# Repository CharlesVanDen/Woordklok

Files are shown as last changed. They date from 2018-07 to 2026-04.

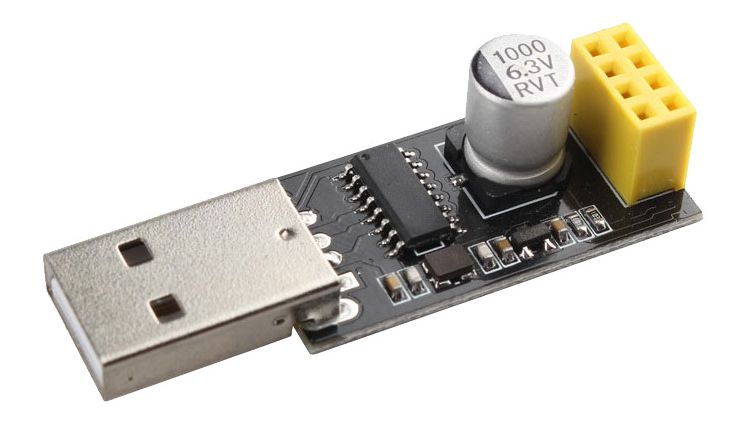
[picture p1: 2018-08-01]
img/ESP01adapter.png

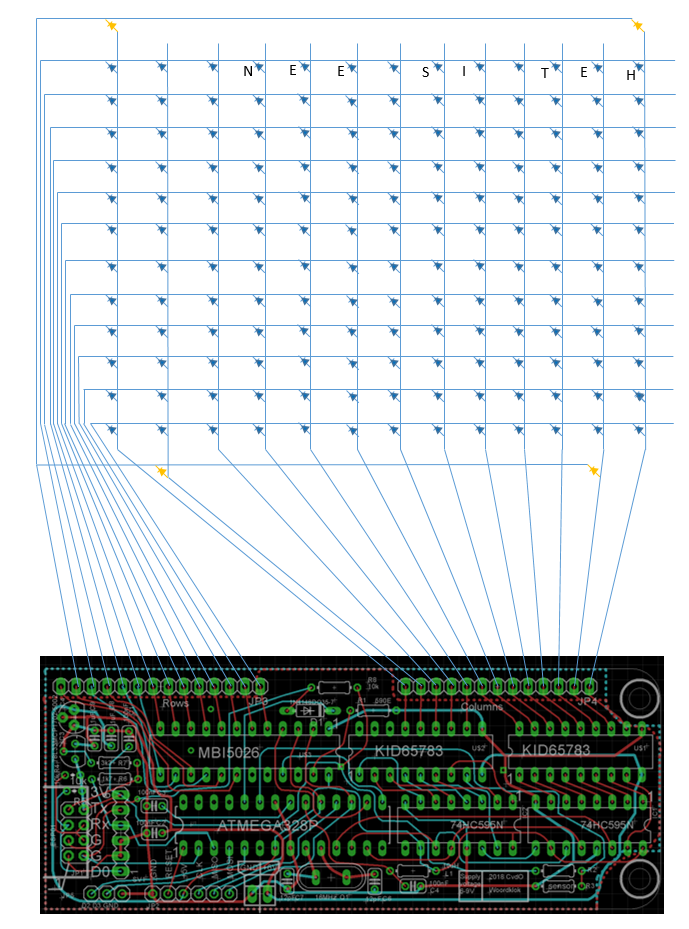
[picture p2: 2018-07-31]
img/Schema hoe de LEDs aan te sluiten.png

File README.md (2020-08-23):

# Woordklok
Alternatieve besturing voor de woordklok van Samenkopen 2016
Dit project bestaat uit:
* een pcb met daarop een ATMEGA en andere elektronica
* een ESP01
* software voor de ATMEGA (Atmel Studio)
* software voor de ESP (Arduino)

Klik op Wiki (hierboven) voor meer informatie

CONTACT: Klik op Wiki (hierboven) en daarna op Bestellen

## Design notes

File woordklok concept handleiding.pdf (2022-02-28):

## Concept

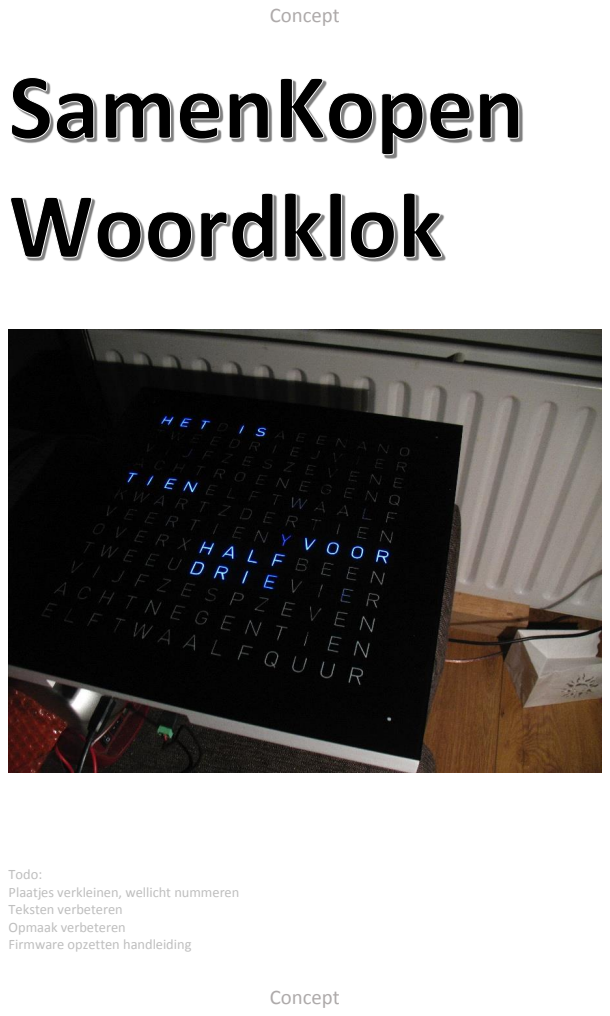
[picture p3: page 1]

Todo:
Plaatjes verkleinen, wellicht nummeren
Teksten verbeteren
Opmaak verbeteren
Firmware opzetten handleiding

# Handleiding in tekst:

Solderen van de LED's
De afstand tussen de LED's is zo dat je geen draden nodig hebt maar van LED naar LED de pootjes kan buigen en verbinden.
Als je de controller voor je hebt met de USB kabel naar je toe gericht, dan zit het positieve deel van de matrix rechtsboven en het negatieve deel linksboven.
Na het solderen krijg je dus verticale en horizontale lijnen. De verticale lijnen(boven naar beneden) zijn de plus(Anode) en de horizontale lijnen(links naar rechts) zijn de min(Kathode).

De magneten
In de doos zitten 16 zeer sterke neodymium magneten. Laat ze niet tegen elkaar aan knallen, dan spatten ze uit elkaar!
1. Vind de polariteit van elke magneet. Bij het plaatsen moeten ze allemaal op dezelfde manier georiënteerd zitten. Bij verkeerde polariteit stoten ze anders af
2. Lijm met seconde of andere sterke lijm eerst 8 magneten in de pockets die in het frame zitten. Druk ze goed aan zodat ze stevig tegen de bodem zitten
3. Leg na het uitharden van de lijm een stukje dun karton op elke magneet.
4. Leg op elk stuk karton een magneet, deze zal direct aangetrokken worden door de andere magneet. Probeer de magneet zo gecentreerd mogelijk te krijgen.
5. Doe een klein druppeltje sterke lijm op elke magneet.
6. Pak het frontpanel en probeer deze zo recht mogelijk op het frame te leggen. Dit doe je door te controleren of het frontpanel perfect aansluit bij elke zijkant van het frame.
7. Leg nu een gewicht, zoals een beker, op de locatie waar elke magneet zit.
8. Niet meer bewegen! Geef voldoende tijd om de lijm te laten uitharden. Haal de kartonnetjes daarna weg en je frontpanel zit goed

Diffuseren van de LED's
Voor een betere lichtverdeling leg je tussen het frame en het frontpanel de witte folie, die je voorzichtig van het frontpanel hebt getrokken. Eventueel plak je deze folie vast.

Bevestigen van de controller aan het frame
Doe wat lijm op de afstandsbusjes van de controller print. Druk de controller print nu stevig tegen de bestemde plek op het frame. Handig om dit eerst te doen voordat je de draden naar de LED's soldeer!

Touch sensoren
De touch sensoren hebben twee aansluitingen aan de achterkant(het groene raster). Sluit maar één draad aan. Het soldeervlak van het raster krijgt géén draad.
Soldeer eerst een draad aan de touch sensor voordat je hem op het frame plakt. Dat is eenvoudiger.

Lichtsensor
De lichtsensor plak je in de sleuf aan de bovenkant van het frame. Het handigste is om twee draden met voldoende lengte te pakken en deze met een boormachine in elkaar te twisten. Dan soldeer je die aan de lichtsensor en die gaat dan in een rechte lijn naar beneden naar de controller. Als je deze draad onder de LED's doorvlecht, dan blijft deze mooi op zijn plek!

# Deel I

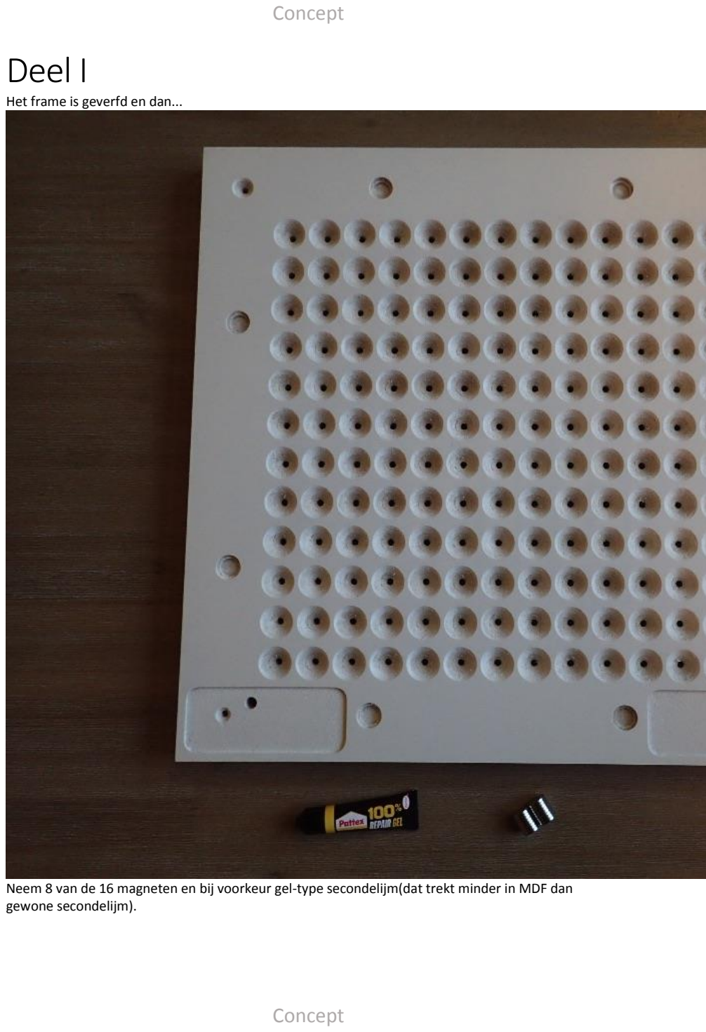
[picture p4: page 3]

Het frame is geverfd en dan...

Neem 8 van de 16 magneten en bij voorkeur gel-type secondelijm(dat trekt minder in MDF dan gewone secondelijm).

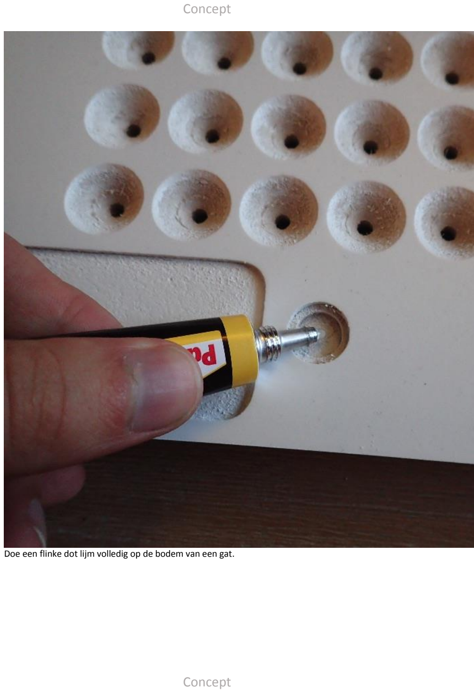
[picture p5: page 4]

Doe een flinke dot lijm volledig op de bodem van een gat.

Leg een magneet op het gat en druk deze met bijvoorbeeld een plastic pen het gat in.
Het gat en de magneet sluiten nauw aan dus het kan even wat kracht en moeite kosten! Druk niet door zodra hij er in glijdt want dan kan je door het frame drukken.

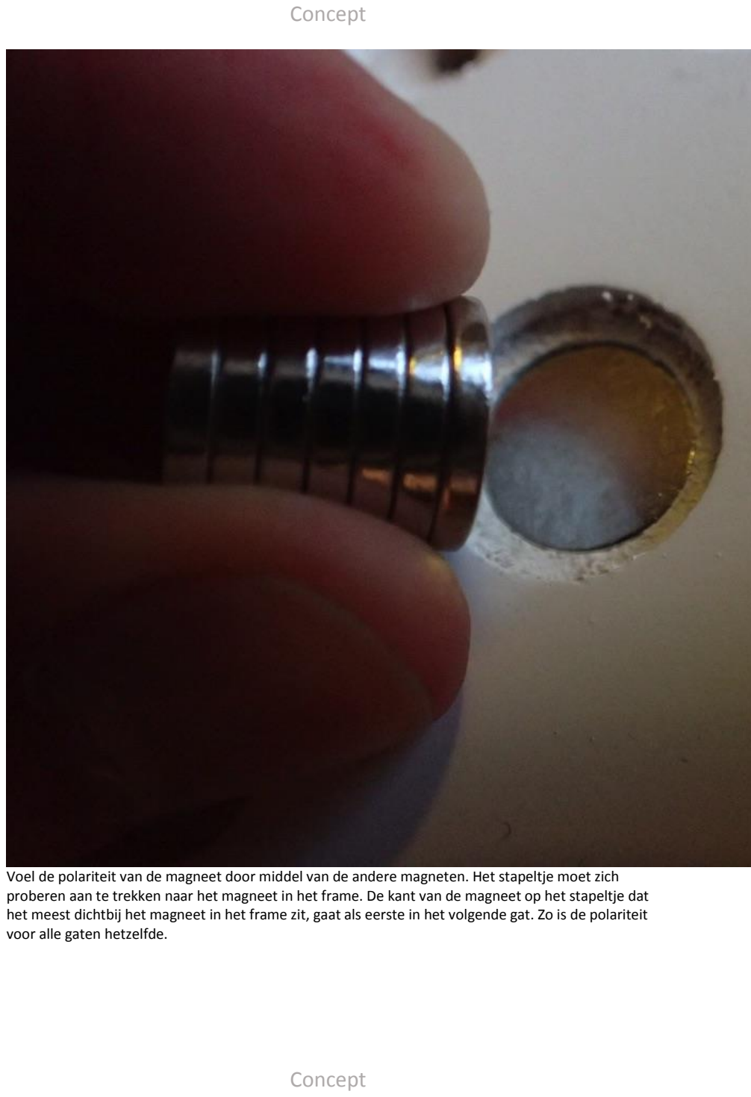
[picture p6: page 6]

Voel de polariteit van de magneet door middel van de andere magneten. Het stapeltje moet zich proberen aan te trekken naar het magneet in het frame. De kant van de magneet op het stapeltje dat het meest dichtbij het magneet in het frame zit, gaat als eerste in het volgende gat. Zo is de polariteit voor alle gaten hetzelfde.

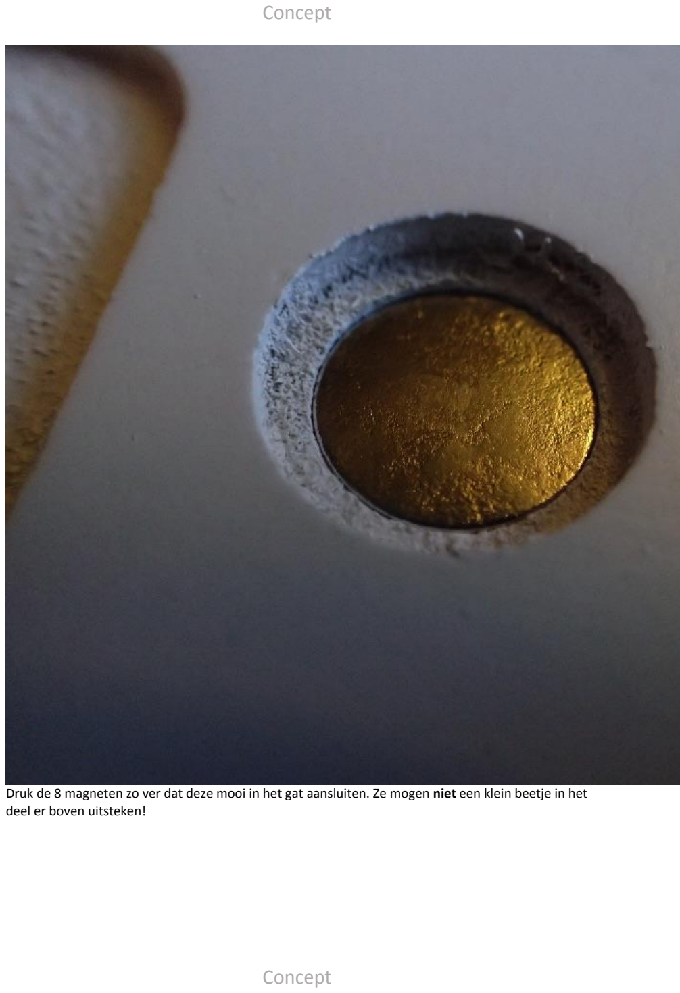
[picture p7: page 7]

Druk de 8 magneten zo ver dat deze mooi in het gat aansluiten. Ze mogen niet een klein beetje in het deel er boven uitsteken!

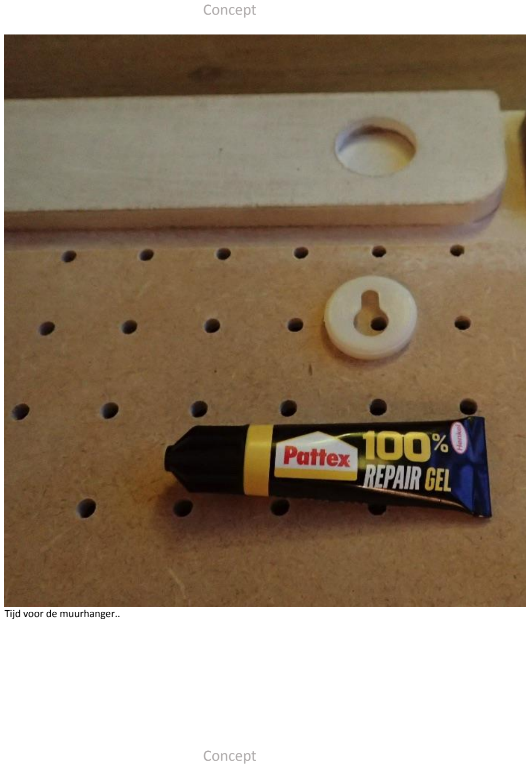
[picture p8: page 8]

Tijd voor de muurhanger..

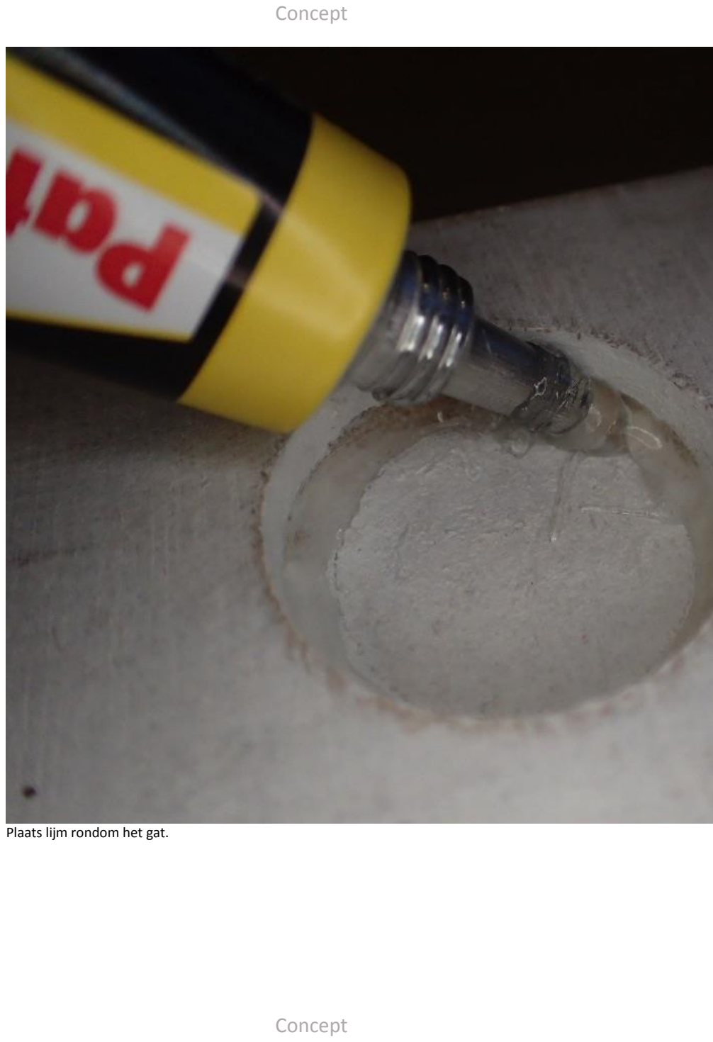
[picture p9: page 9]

Plaats lijm rondom het gat.

Leg de muurhanger op de juiste manier neer en druk deze het gat in. Hij zal een stukje verzonken liggen.

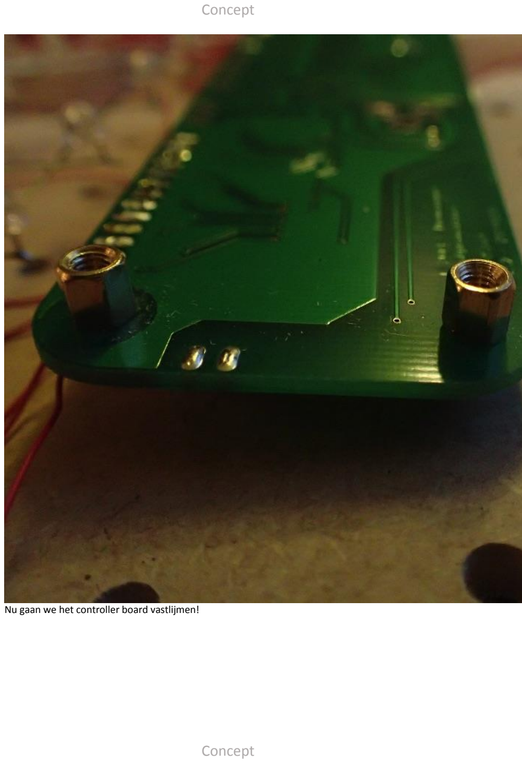
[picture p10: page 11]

Nu gaan we het controller board vastlijmen!

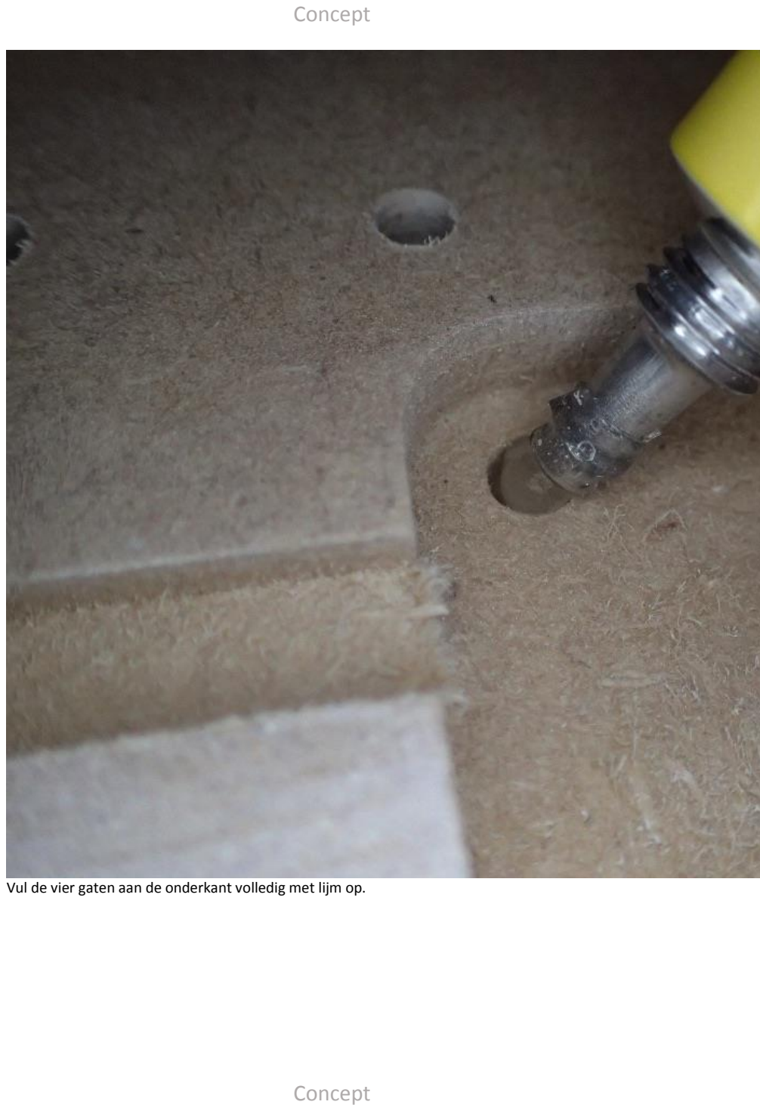
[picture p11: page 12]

Vul de vier gaten aan de onderkant volledig met lijm op.

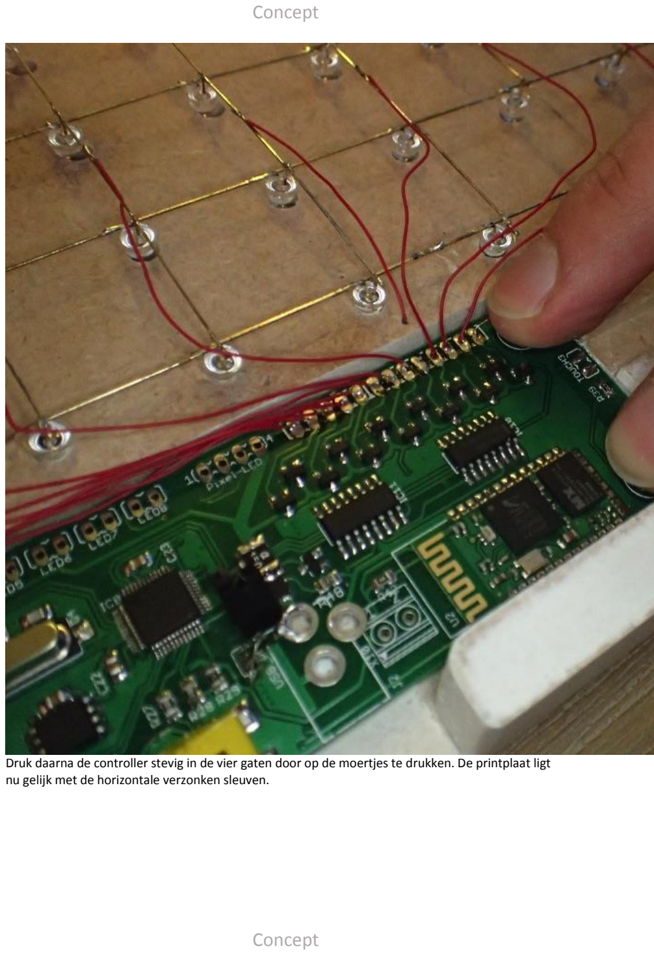
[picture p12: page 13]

Druk daarna de controller stevig in de vier gaten door op de moertjes te drukken. De printplaat ligt nu gelijk met de horizontale verzonken sleuven.

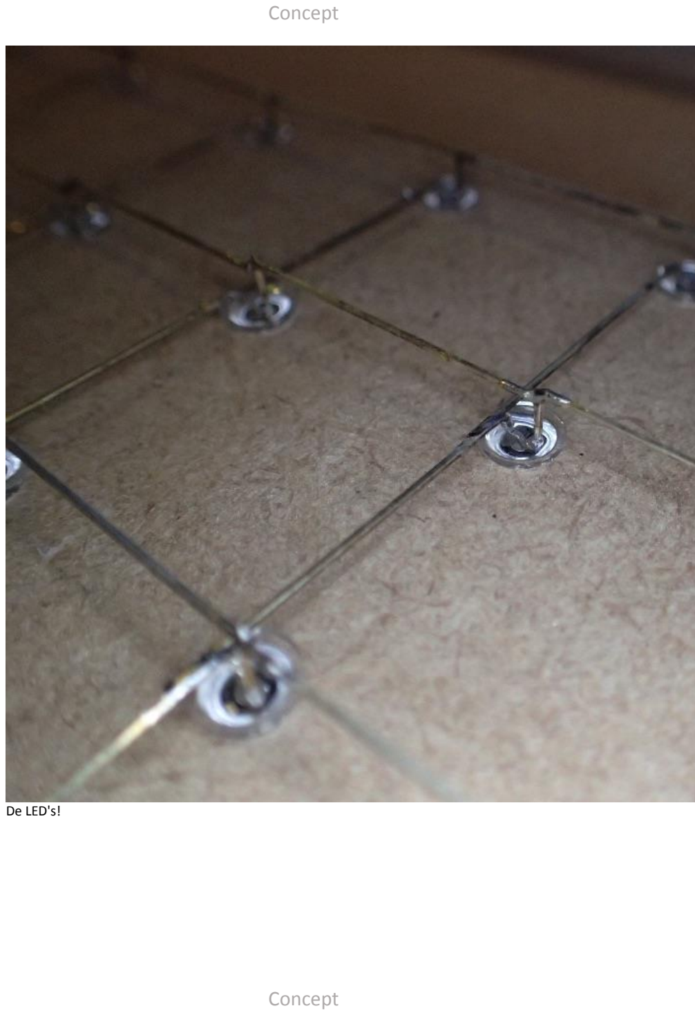
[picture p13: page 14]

De LED's!

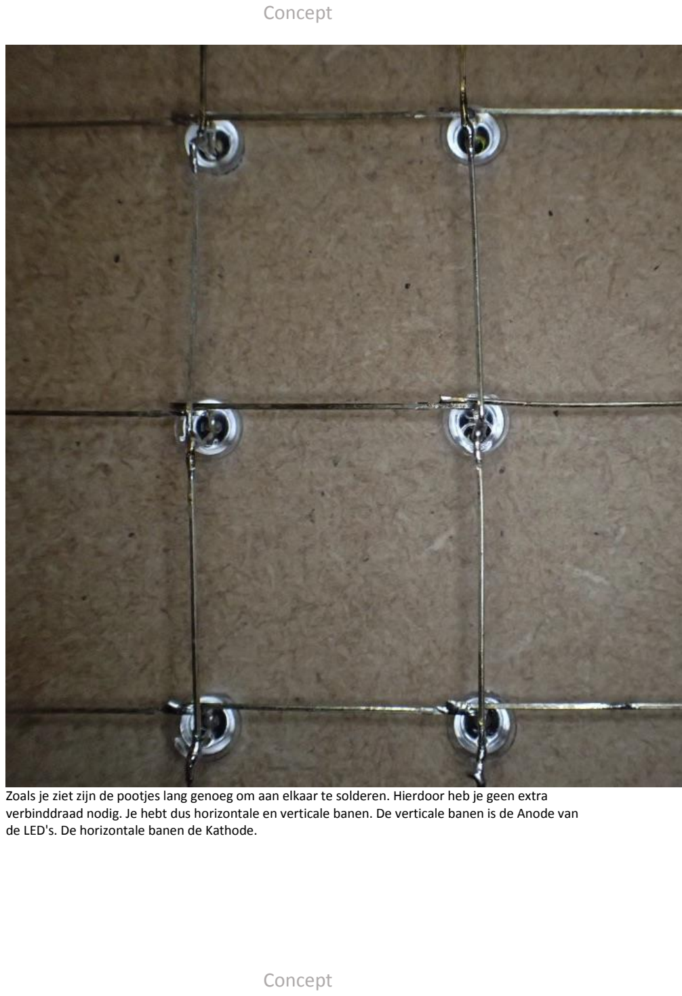
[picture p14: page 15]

Zoals je ziet zijn de pootjes lang genoeg om aan elkaar te solderen. Hierdoor heb je geen extra verbinddraad nodig. Je hebt dus horizontale en verticale banen. De verticale banen is de Anode van de LED's. De horizontale banen de Kathode.

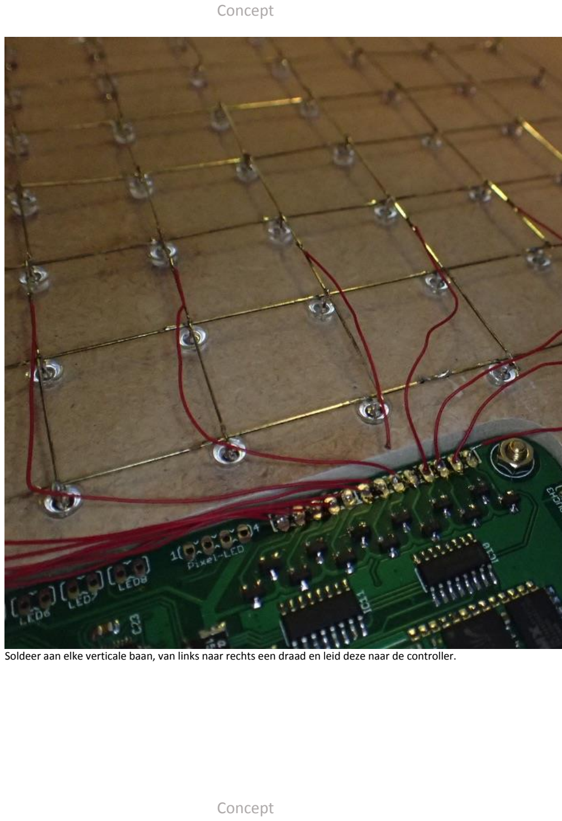
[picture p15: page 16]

Soldeer aan elke verticale baan, van links naar rechts een draad en leid deze naar de controller.

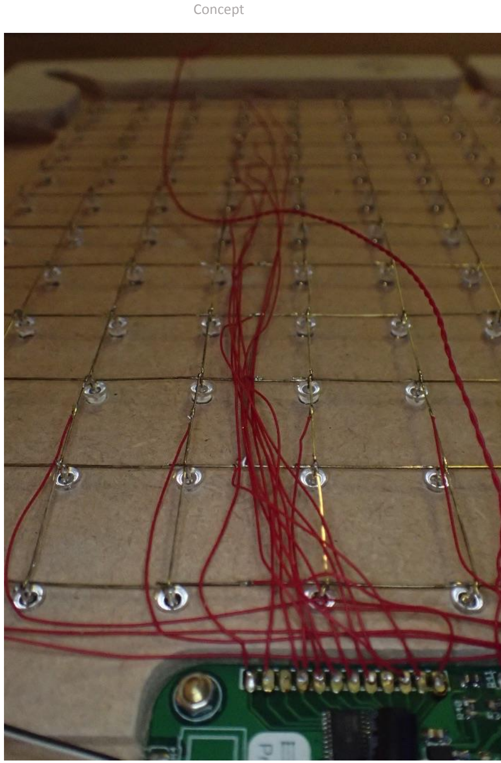
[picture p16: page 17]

Natuurlijk ook voor de verticale banen! Bij voorkeur laat je de draden onder de LED poten lopen(op de foto is dus fout), dan blijven de draden mooi tegen het frame aan zitten.

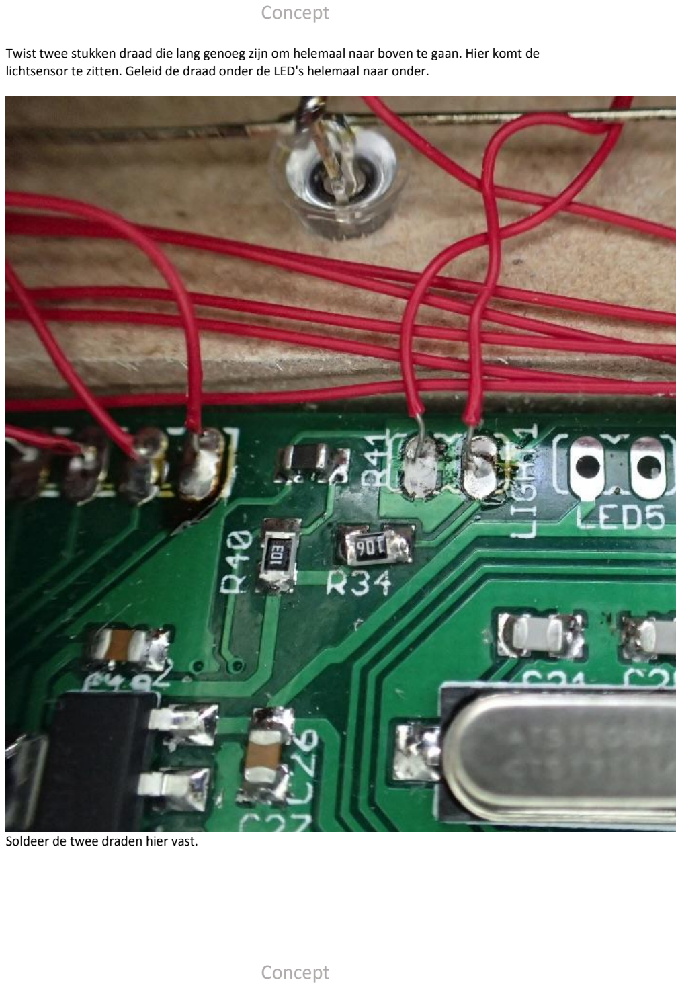
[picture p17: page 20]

Twist twee stukken draad die lang genoeg zijn om helemaal naar boven te gaan. Hier komt de lichtsensor te zitten. Geleid de draad onder de LED's helemaal naar onder.

Soldeer de twee draden hier vast.

# Deel II

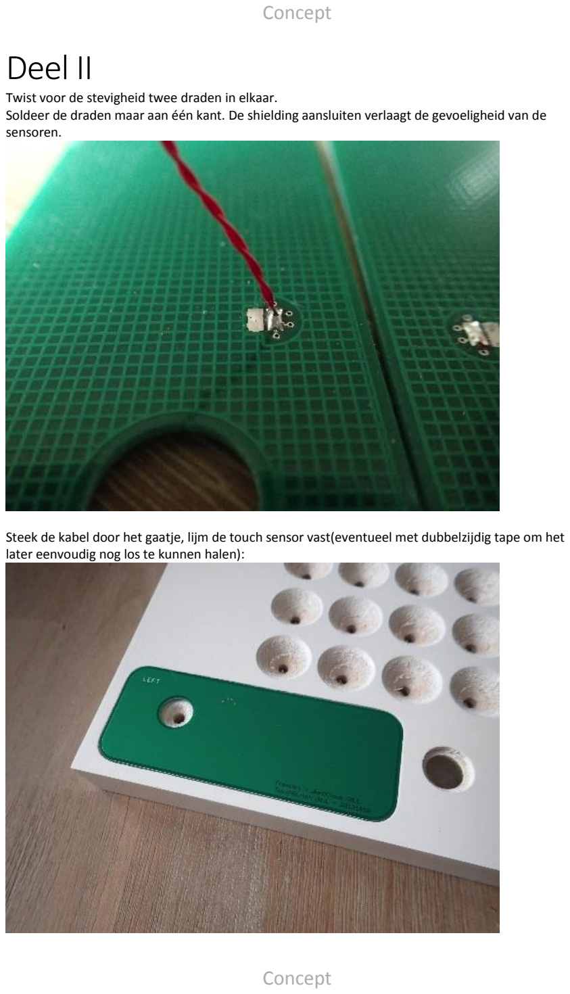
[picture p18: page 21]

Twist voor de stevigheid twee draden in elkaar.
Soldeer de draden maar aan één kant. De shielding aansluiten verlaagt de gevoeligheid van de sensoren.

Steek de kabel door het gaatje, lijm de touch sensor vast(eventueel met dubbelzijdig tape om het later eenvoudig nog los te kunnen halen):

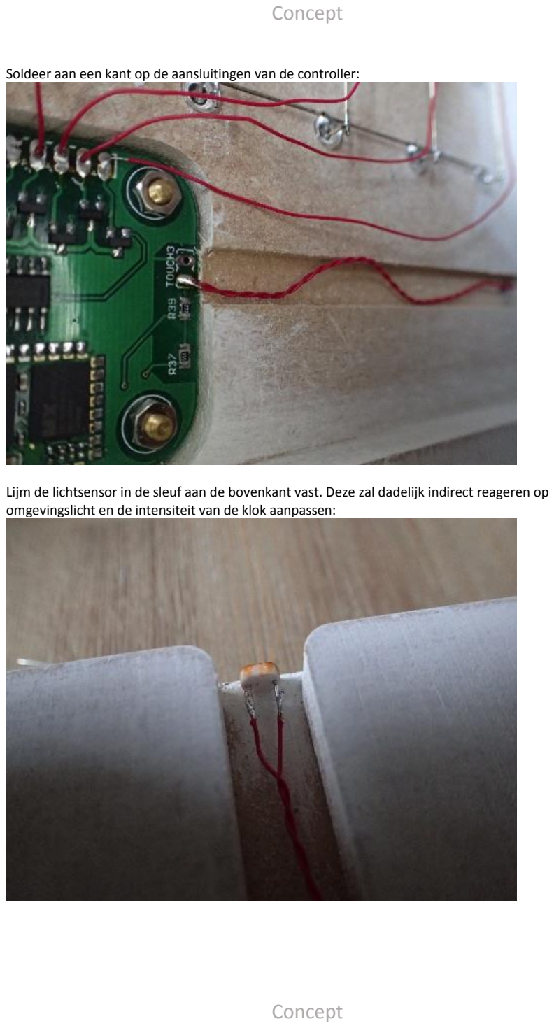
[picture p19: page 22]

Soldeer aan een kant op de aansluitingen van de controller:

Lijm de lichtsensor in de sleuf aan de bovenkant vast. Deze zal dadelijk indirect reageren op omgevingslicht en de intensiteit van de klok aanpassen:

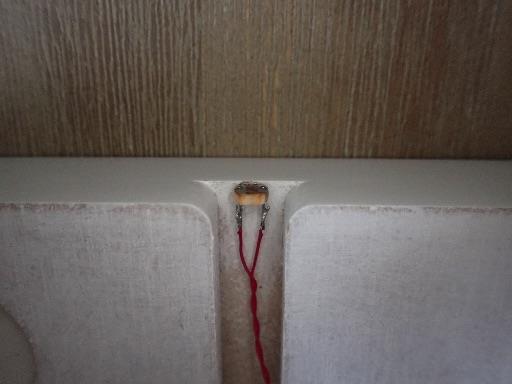
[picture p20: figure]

Frontpanel

De volgende onderdelen heb je nodig om het frontpanel aan de overige 8 magneten vast te lijmen. De flesjes bier kan je de komende 24 uur niet aanraken.

Kleine kartonnetjes(van bijvoorbeeld een pakje van de Knorr) zorgen er voor dat de magneten afstand van elkaar houden:

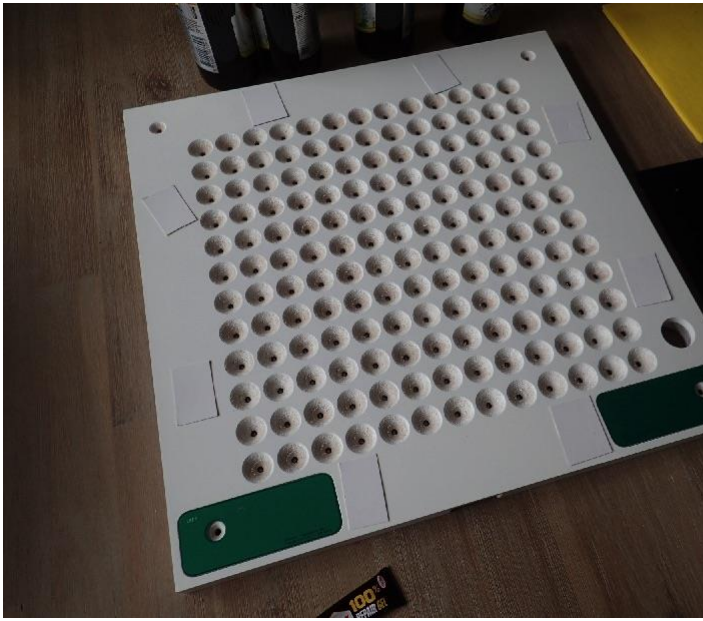
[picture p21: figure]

Leg de magneten hierop. Ze zullen automatisch centreren(dit kan je voelen!)

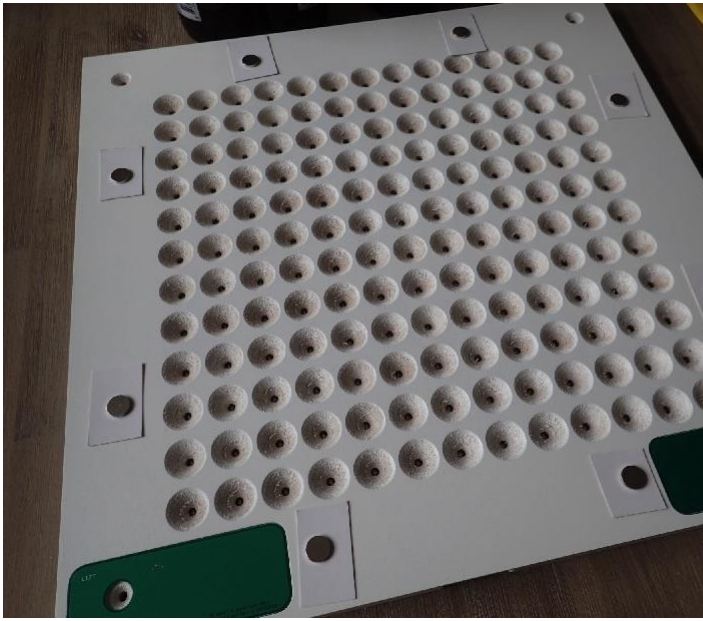
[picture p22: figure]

Voldoende lijm op elke magneet doen:

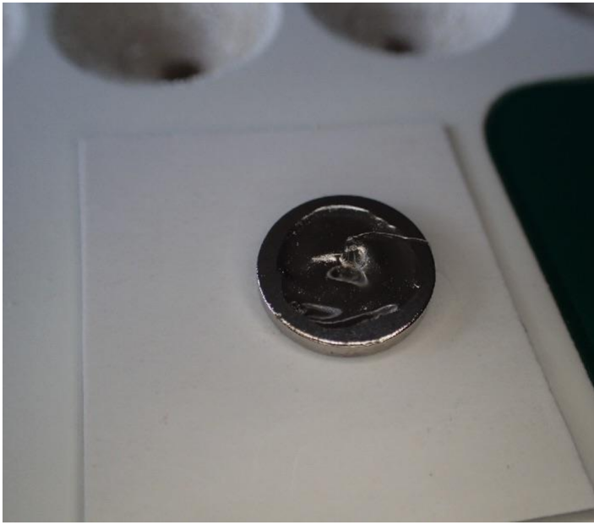
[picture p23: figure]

Leg het frontpanel zo recht mogelijk op de magneten:

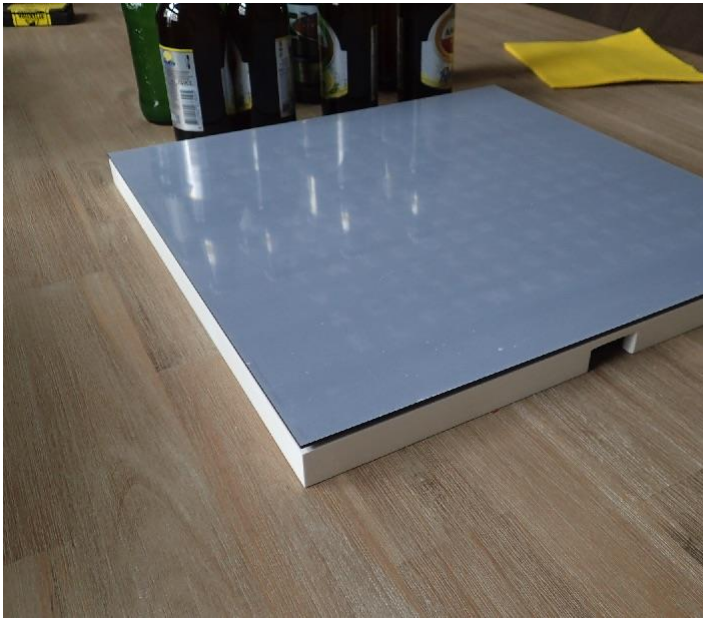
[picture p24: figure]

Zorg dat de uitlijning met alle randen klopt. Dit kan je controleren door een haaks blok tegen het frame aan te leggen:

Voscose doekjes die je in de keuken kan vinden zorgen er voor dat de flesjes/het gewicht het frontpanel niet kan beschadigen:

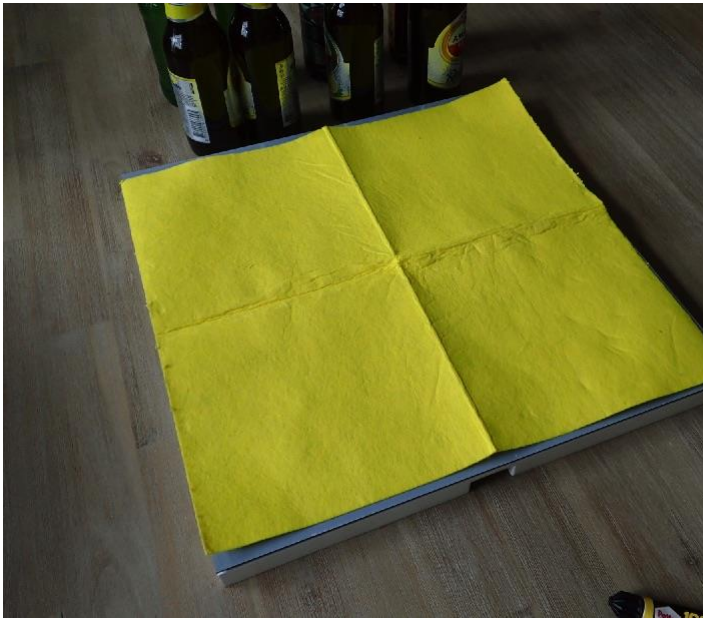
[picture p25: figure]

Zet de bierflesjes zo goed mogelijk op de magneten. Dit zorgt voor een strakke lijmverbinding.

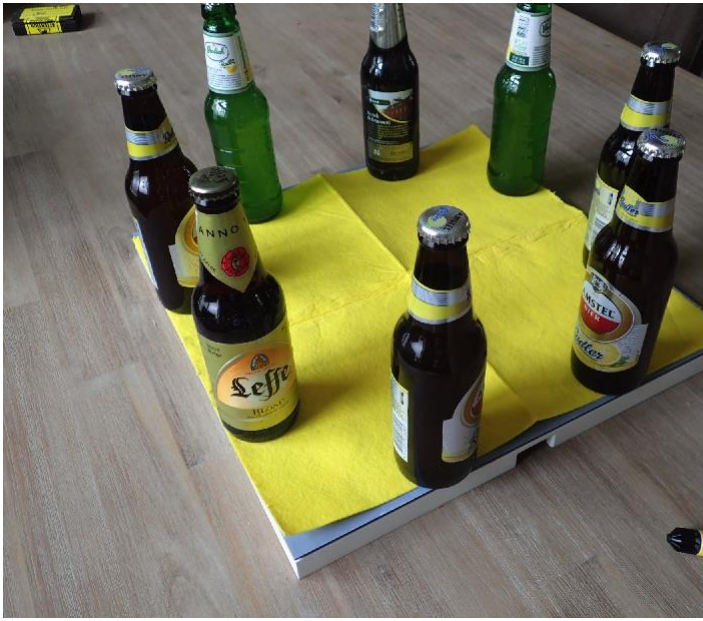
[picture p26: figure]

Nu zal je 24 uur moeten wachten tot de lijm volledig is uitgehard..

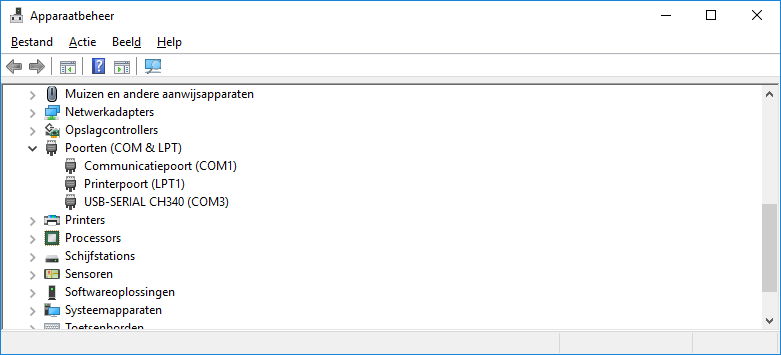
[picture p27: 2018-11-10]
img/apparaatbeheer2.png

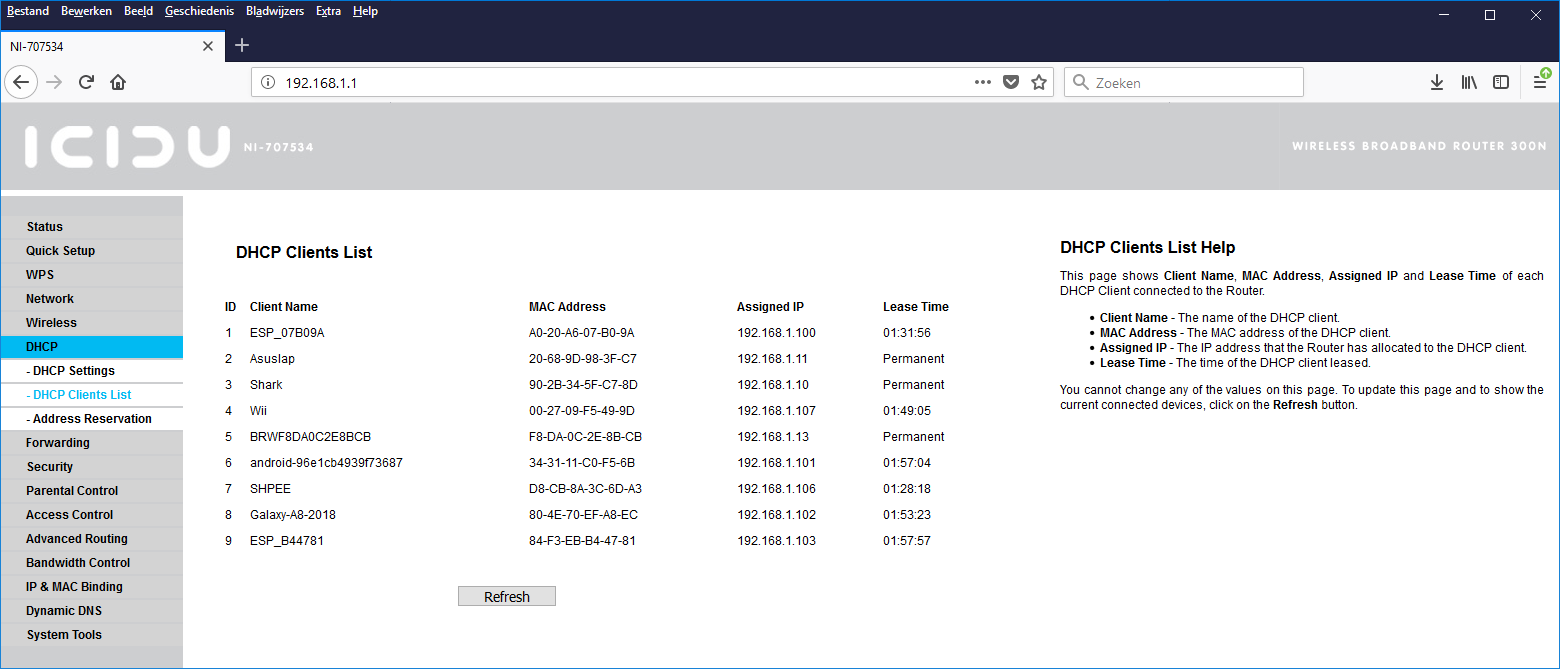
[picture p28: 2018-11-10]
img/router.png

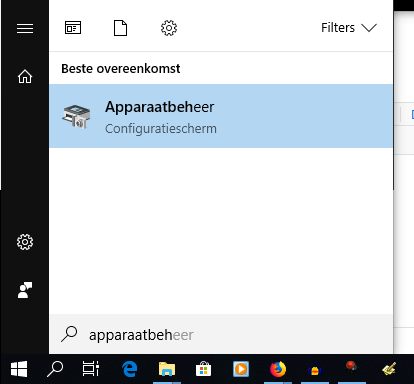
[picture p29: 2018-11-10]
img/apparaatbeheer.png

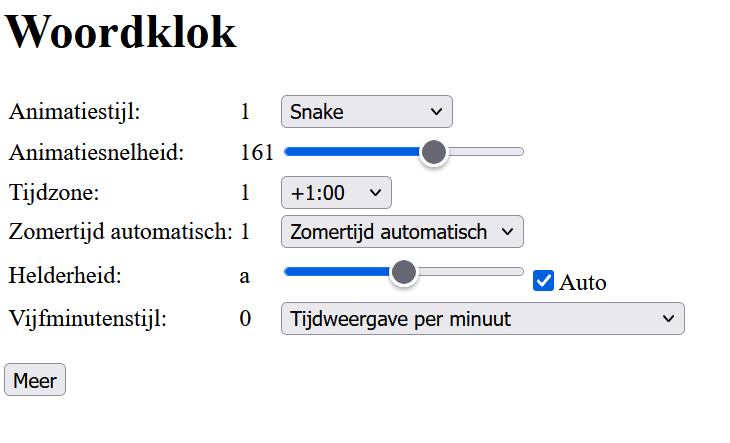
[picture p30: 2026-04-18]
img/woordklokwebpage.png

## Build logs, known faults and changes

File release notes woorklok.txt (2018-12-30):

Features woordklok versie 2.0, Dec 2018

Deze versie bestaat uit:
WoordklokCharles.c (software voor de ATMEGA, compileren met ATMEL STUDIO)
ESP01WifiManager.ino (software voor de ESP01, compileren met Arduino)

Nieuwe features:
* Klok toont IP-adres
* Homepagina http://<ip-adres> toont alle instellingen en menu's om de instellingen te veranderen.
* Nieuwe animatie-mogelijkheden: uit, Snake en Rain. De bestaande animatie heet nu Snail.
Snake animatie beweegt niet alleen horizontaal zig zag maar ook verticaal en is daardoor sneller
Rain animatie veegt van boven naar benden over het display
Animatie instellen: set?a=0 (uit) set?a=1 (snake) 2 (snail) 3 (rain)
Animatiesnelheid: set?s=99
* Helderheid aanpasbaar: vaste waarde: http://ip-adres/set?b=7..230
Helderheid uit: http://ip-adres/set?b=0
Helderheid automatisch: http://ip-adres/set?b=a (a=auto)
* Status van de ESP01 opvragen met http://<ip-adres>/esp
* Status klok (ATMEGA) opvragen met http://<ip-adres>/status
* Instellingen aanpassen gaat met http://<ip-adres>/set?x=y
	set?d=0 (uit) of set?d=1 (aan) zomertijd
	set?z=1 tijdzone
	set?f=1 Vijfminutenmodus: f=0: toon iedere minuut. f=1: rond naar beneden af op 5 min. De hoekleds tonen de extra minuten (1, 2, 3 of 4 brandende LEDS). f=2: rond af naar de dichtstbijzijnde 5 minuten. 1 of 2 LEDs rechts tonen extra minuten. 1 of 2 LEDs links tonen dat naar boven is afgerond.
* al deze instellingen worden in EEPROM opgeslagen
* Voor testdoeleinden gebruik ik de volgende opdrachten om tijd en datumopdrachten naar de ATMEGA te sturen.
set?x=<T23:50:00>
set?x=<D2018-08-13>
Deze opdrachten worden wel binnen 10 minuten overruled door een normale time en date vanuit NTP.
* De 5-mintenmodi tonen rond het hele en halve uur de tekst "even voor" of "na"
* ATMEGA stuurt een json object waarin alle gegevens als antwoord op status
* Programmeren van de ESP in-circuit is nu beschreven op wiki github
* Serial io buffering waardoor zomertijdprobleem minder vaak voorkomt

Fixed bugs:
* Bij het ophalen van de status breekt het resultaat af:
<S>Woordklok OK;T=2018-12-26T12:05:32+0100;192.168.1.100;anim=1-200;zone=1+1;briS>. Het was de buffer size in de ESP01
* 12:16 (met five=2) wordt kwart voor half twee
* 12:58 wordt het is twee
* IE haalt status en esp uit cache. Fix: Expires: -1 header toegevoegd
Warning: tekenset is niet gedefinieerd. Fix: "text/html; charset=UTF-8"
* Same Origin Policy (CORS) weer dichtgezet (om weer open te zetten: uncomment de CORS regel in de ESP01 code)

Todo:

Known Bugs:

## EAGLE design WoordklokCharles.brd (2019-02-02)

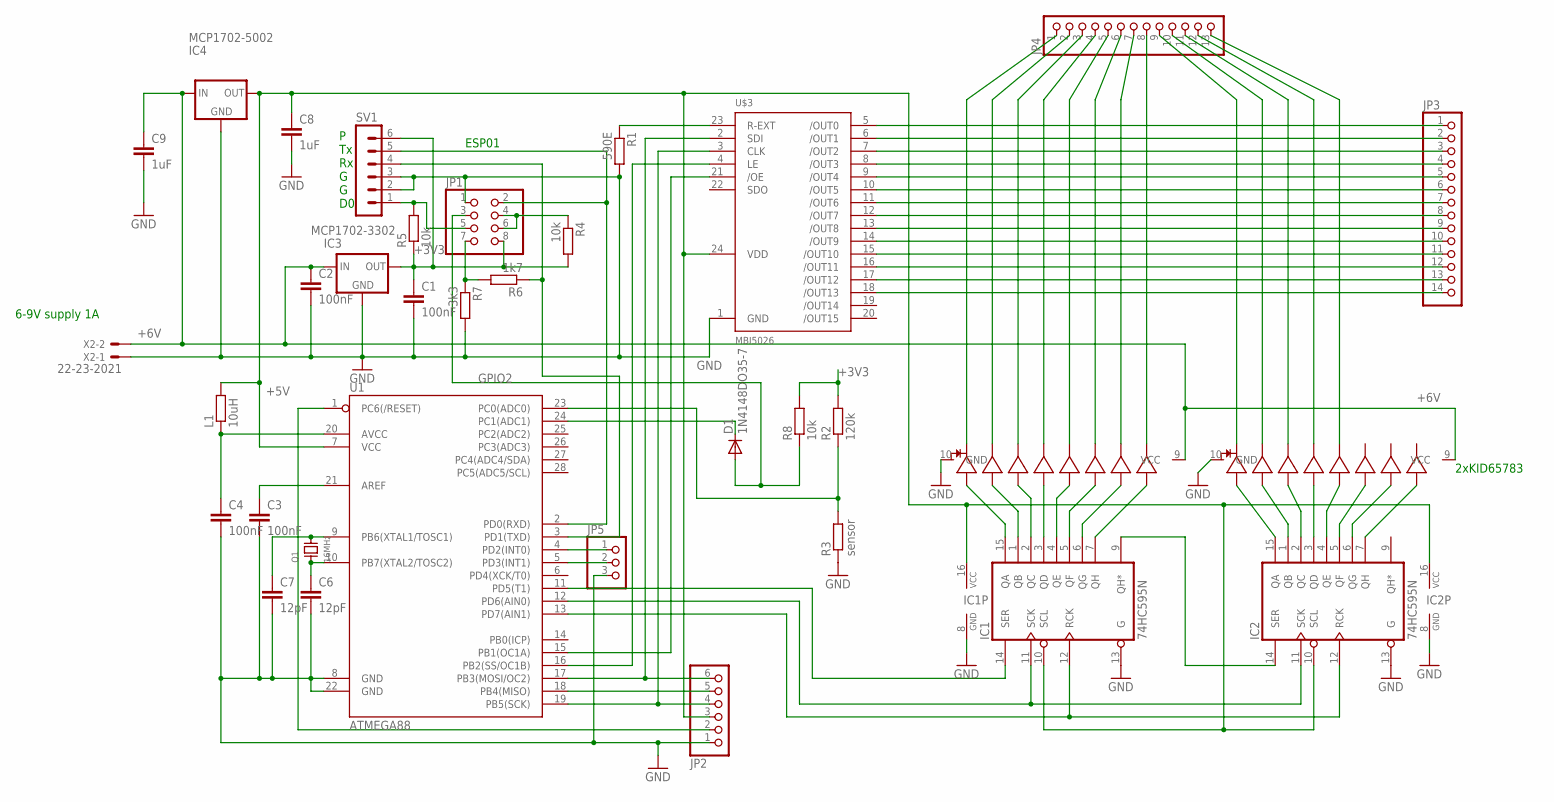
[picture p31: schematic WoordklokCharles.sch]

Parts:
C1, C2, C3, C4: 100nF; C025-024X044
C6, C7: 12pF; C025-024X044
C8, C9: 1uF; C025-024X044
D1: 1N4148DO35-7; DO35-7
IC1, IC2: 74HC595N; DIL16
IC3: MCP1702-3302; TO92
IC4: MCP1702-5002; TO92
JP1: PINHD-2X4; 2X04
JP2: PINHD-1X6; 1X06
JP3: PINHD-1X14; 1X14
JP4: PINHD-1X13; 1X13
JP5: PINHD-1X3; 1X03
L1: 10uH; 0204/7
Q1: 16MHz; XTAL
R1: 590E; 0204/7
R2: 120k; 0204/7
R3: sensor; 0204/7
R4, R5: 10k; 0204V
R6: 1k7; 0204/7
R7: 3k3; 0204/7
R8: 10k; 0204/7
SV1: MA06-1
U1: ATMEGA88; DIL28-3
U$1, U$2: KID65783; DIP18
U$3: MBI5026; DIP24
X2: 22-23-2021

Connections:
+3V3: C1.1, IC3.3 (OUT), JP1.8, R2.2, R4.2, R5.1, R8.2, SV1.6
+5V: C8.1, IC1.10 (SCL), IC1.16 (VCC), IC2.10 (SCL), IC2.16 (VCC), IC4.3 (OUT), JP2.3, L1.2, U1.7 (VCC), U$3.24 (VDD)
+6V: C2.1, C9.1, IC3.2 (IN), IC4.2 (IN), U$1.9 (VCC), U$2.9 (VCC), X2.2
AVCC: C4.1, L1.1, U1.20 (AVCC)
ESP2: JP1.2, SV1.5, U1.2 (PD0(RXD))
ESP7: R6.1, SV1.4, U1.3 (PD1(TXD))
GND: C1.2, C2.2, C3.2, C4.2, C6.2, C7.2, C8.2, C9.2, IC1.8 (GND), IC1.13 (G), IC2.8 (GND), IC2.13 (G), IC3.1 (GND), IC4.1 (GND), JP1.1, JP2.1, JP5.3, R1.2, R3.1, R7.2, SV1.2, SV1.3, U1.8 (GND), U1.22 (GND), U$1.10 (GND), U$2.10 (GND), U$3.1 (GND), X2.1
GPIO2: D1.A, JP1.3, R8.1
unnamed: IC1.15 (QA), U$1.8 (IN7)
unnamed: IC1.1 (QB), U$1.7 (IN6)
unnamed: IC1.2 (QC), U$1.6 (IN5)
unnamed: IC1.3 (QD), U$1.5 (IN4)
unnamed: IC1.4 (QE), U$1.4 (IN3)
unnamed: IC1.5 (QF), U$1.3 (IN2)
unnamed: IC1.6 (QG), U$1.2 (IN1)
unnamed: IC1.7 (QH), U$1.1 (IN0)
unnamed: IC2.15 (QA), U$2.8 (IN7)
unnamed: IC2.1 (QB), U$2.7 (IN6)
unnamed: IC2.2 (QC), U$2.6 (IN5)
unnamed: IC2.3 (QD), U$2.5 (IN4)
unnamed: IC2.4 (QE), U$2.4 (IN3)
unnamed: IC2.5 (QF), U$2.3 (IN2)
unnamed: IC2.6 (QG), U$2.2 (IN1)
unnamed: IC2.7 (QH), U$2.1 (IN0)
unnamed: IC1.9 (QH*), IC2.14 (SER)
unnamed: IC1.12 (RCK), IC2.12 (RCK), U1.13 (PD7(AIN1))
unnamed: IC1.11 (SCK), IC2.11 (SCK), U1.12 (PD6(AIN0))
unnamed: JP4.8, U$1.18 (OUT0)
unnamed: JP4.13, U$2.15 (OUT3)
unnamed: JP4.1, U$1.11 (OUT7)
unnamed: JP4.2, U$1.12 (OUT6)
unnamed: JP4.3, U$1.13 (OUT5)
unnamed: C3.1, U1.21 (AREF)
unnamed: JP3.2, U$3.6 (/OUT1)
unnamed: JP3.1, U$3.5 (/OUT0)
unnamed: R1.1, U$3.23 (R-EXT)
unnamed: JP1.5, R5.2, SV1.1
unnamed: JP1.4, JP1.6, R4.1
unnamed: JP2.4, U1.19 (PB5(SCK)), U$3.3 (CLK)
unnamed: JP2.6, U1.17 (PB3(MOSI/OC2)), U$3.2 (SDI)
unnamed: U1.16 (PB2(SS/OC1B)), U$3.4 (LE)
unnamed: IC1.14 (SER), U1.11 (PD5(T1))
unnamed: JP5.1, U1.4 (PD2(INT0))
unnamed: JP5.2, U1.5 (PD3(INT1))
unnamed: R2.1, R3.2, U1.23 (PC0(ADC0))
unnamed: JP2.5, U1.18 (PB4(MISO))
unnamed: JP2.2, U1.1 (PC6(/RESET))
unnamed: JP4.4, U$1.14 (OUT4)
unnamed: JP4.5, U$1.15 (OUT3)
unnamed: C7.1, Q1.P$2, U1.9 (PB6(XTAL1/TOSC1))
unnamed: C6.1, Q1.P$1, U1.10 (PB7(XTAL2/TOSC2))
unnamed: JP4.6, U$1.16 (OUT2)
unnamed: JP4.7, U$1.17 (OUT1)
unnamed: U1.15 (PB1(OC1A)), U$3.21 (/OE)
unnamed: JP4.9, U$2.11 (OUT7)
unnamed: JP4.10, U$2.12 (OUT6)
unnamed: JP4.11, U$2.13 (OUT5)
unnamed: JP4.12, U$2.14 (OUT4)
unnamed: JP3.14, U$3.18 (/OUT13)
unnamed: JP3.3, U$3.7 (/OUT2)
unnamed: JP3.4, U$3.8 (/OUT3)
unnamed: JP3.5, U$3.9 (/OUT4)
unnamed: JP3.6, U$3.10 (/OUT5)
unnamed: JP3.7, U$3.11 (/OUT6)
unnamed: JP3.8, U$3.12 (/OUT7)
unnamed: JP3.9, U$3.13 (/OUT8)
unnamed: JP3.10, U$3.14 (/OUT9)
unnamed: JP3.11, U$3.15 (/OUT10)
unnamed: JP3.12, U$3.16 (/OUT11)
unnamed: JP3.13, U$3.17 (/OUT12)
unnamed: JP1.7, R6.2, R7.1
unnamed: D1.C, U1.24 (PC1(ADC1))

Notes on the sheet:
2xKID65783
ESP01
P Tx Rx G G D0
6-9V supply 1A

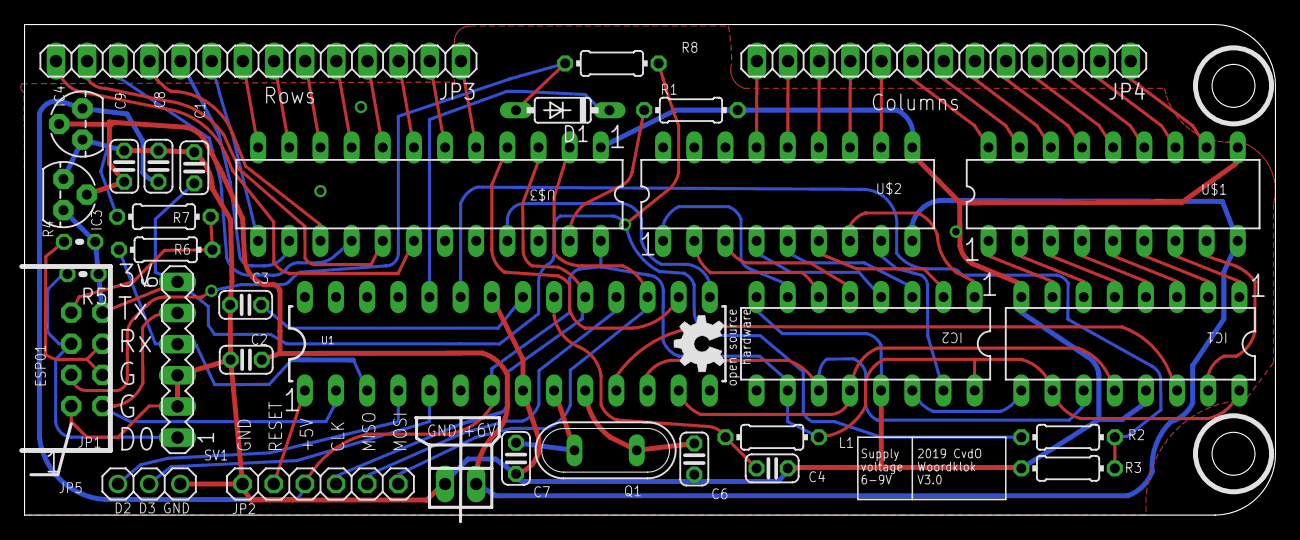
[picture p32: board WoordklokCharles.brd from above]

Board: 2 copper layers, 102.0 x 40.0 mm, 35 parts (1 on the bottom side), 72 nets.

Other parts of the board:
U$4: OSHW_5MM

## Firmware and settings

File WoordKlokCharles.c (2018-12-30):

/*
 * WoordKlokCharles.c
 *
 * Created: 6-4-2018 14:10:04
 * Version: 9 JULY 2018, bug in het woord EEN gecorrigeerd
 *  Author: Charles van den Ouweland
 Alternatief voor de originele controller voor de woordklok van samenkopen,
 gebaseerd op een AVR controller i.c.m. een ESP01 module om de tijd op te halen via wifi
 Met een printplaat met geheel through hole componenten.
 
 ATMEGA88PA <-- check uctrler type before compiling!
 16MHz crystal
 
 connect:
 ATMEGA88 pin       MBI5026 pin (rows/cathodes of the leds)
 MOSI PB3 pin 17 to SDI pin 2
 SCK  PB5 pin 19 to CLK pin 3
 SS   PB2 pin 16 to LE  pin 4
      PB1 pin 15 to OE  pin 21
 ATMEGA88 pin       74HC595 pin (and then to KID65783 to the columns/anodes of leds)
 PD5                SDI pin 14
 PD6                CLK pin 11
 PD7                RCK pin 12

The MBI5026 is attached to the SPI pins of the ATMEGA, whereas the 74HC595's are done by software.
This is not a big deal as we clock one 1 into the 74HC595 and then shift that 1 through the shift register just 1 clock pulse at a time.
 
 */ 

#include <avr/io.h>
#include <avr/interrupt.h>
#include <avr/eeprom.h>
#include <stdlib.h>

#define SOFTWARE_VERSION "2.0"

#define UREN_OFFSET 16
#define HET 0
#define IS 29
#define VOOR 30
#define OVER 31
#define HALF 32
#define UUR 33
#define SEC00_14 34
#define SEC15_29 35
#define SEC30_44 36
#define SEC45_59 37
#define NUL_EXTRA 38
#define T_FOR_TWEE 39
#define I_FOR_IP 42
#define A_FOR_ADRES 44
#define EVEN 47
#define NA 48

#define EEPROM_ANIM_SPEED 0
#define EEPROM_ANIM_STYLE 1
#define EEPROM_DST_ENABLED 2
#define EEPROM_TIMEZONE 3
#define EEPROM_BRIGHTNESS 4
#define EEPROM_FIVEMINSTYLE 5

#define NUM_COLUMNS 13
#define KLKDBG 0
#define pixel16_t volatile uint16_t
#define BUFFYSIZE 40
#define LEUK 1

void displayTime();//show the current time on the wordclock
void displayNumber(uint8_t n); //show a number (0...254) on the wordclock
void display_text_ipadress(); //show the text "ip adres" on the woordklok

void printchar(char c);
void print(char*s);
void printint2(uint8_t n);
void printuint(uint8_t n);
uint8_t calcDST();
void checkSerialinput(char k);
void checkLdr();
void setlin(uint8_t index,uint8_t value, pixel16_t*matrix);
uint8_t getlin(uint8_t index, pixel16_t*matrix);


/* LAYOUT DER KLOCK

HETDISAEENANO
TWEEDRIEJVIER
VIJFZESZEVENE
ACHTROENEGENQ
TIENELFTWAALF
KWARTZDERTIEN
VEERTIENYVOOR
OVERXHALFBEEN
TWEEUDRIEVIER
VIJFZESPZEVEN
ACHTNEGENTIEN
ELFTWAALFQUUR

*/

static const uint8_t coordinaten[]={ //ROW, COLUMN, LENGTH
	1,0,3, //HET 0
	1,7,3, //EEN minuten 1
	2,0,4, //TWEE 2
	2,4,4, //DRIE 3
	2,9,4, //VIER 4
	3,0,4, //VIJF 5
	3,4,3, //ZES 6
	3,7,5, //ZEVEN 7
	4,0,4, //ACHT 8
	4,7,5, //NEGEN 9
	5,0,4, //TIEN 10
	5,4,3, //ELF 11
	5,7,6, //TWAALF 12
	6,6,7, //DERTIEN 13
	7,0,8, //VEERTIEN 14
	6,0,5, //KWART 15
	7,10,1, //NUL 16
	8,10,3,//EEN (uren) 17
	9,0,4, //TWEE 18
	9,5,4, //DRIE 19
	9,9,4, //VIER 20
	10,0,4,//VIJF 21
	10,4,3,//ZES 22
	10,8,5,//ZEVEN 23
	11,0,4,//ACHT 24
	11,4,5,//NEGEN 25
	11,9,4,//TIEN 26
	12,0,3,//ELF 27
	12,3,6,//TWAALF 28
	1,4,2, //IS 29
	7,9,4, //VOOR 30
	8,0,4, //OVER 31
	8,5,4, //HALF 32
	12,10,3,//UUR 33
	0,12,1, //SEC00_14 34 de vier hoekleds zitten op rij 0
	0,11,1, //SEC15_29 35
	0,1,1,  //SEC30_44 36
	0,0,1,  //SEC45_59 37
	7,11,1, //NUL_EXTRA 38
	5,0,1,  //T_FOR_TWEE 39
	6,1,1, //W_FOR_TWEE 40
	7,1,2, //EE_FOR_TWEE 41
	9,7,1, //I_FOR_IP 42
	10,7,1,//P_FOR_IP 43
	1,6,1, //A_FOR_ADRES 44
	2,4,2, //DR_FOR_ADRES 45
	3,5,2, //ES_FOR_ADRES 46
	3,8,4, //EVEN 47
	1,9,2, //NA 48
	0
};

volatile uint8_t jaar=0;//alleen de laatste twee cijfers van het jaar.
volatile uint8_t maand=0;
volatile uint8_t dag=0;
volatile uint8_t uur=0;
volatile uint8_t min=0;
volatile uint8_t sec=0;
volatile uint8_t tic=0;
static uint8_t timezone; //lokale tijdzone: 1 uur verschil met UTC
volatile uint8_t dst=0; //daglight saving time (zomertijd)
uint8_t lastSundayInOctober;//end of DST
uint8_t lastSundayInMarch;//start of DST
uint8_t displayMode=0; //mode: 0=display time; 1=display ip address 
uint8_t displayIpIndex=0; //when displaying the ip adres: which digit?
uint8_t ipadress[4];
uint8_t anim_speed;
uint16_t anim_delay; //determines the speed of the animation
uint8_t anim_style; //0=no animation, 1=snake animation, 2=snail animation
uint8_t dst_enabled;//zomertijd or daylight saving time enabled
uint8_t five_min_style; //0: change time display every minute; 1: round down to five minutes, 2: round to nearest 5 min

//variables for the LDR
uint16_t sumLdrSamples=0;
uint8_t numLdrSamples=0;
uint8_t brightnessFixed=0;

uint8_t bufindex=255;
char buf[13];
volatile char buffy[BUFFYSIZE]; //input buffer for serial io
volatile uint8_t buffyIndex=0;//first empty byte

static pixel16_t mypixels[NUM_COLUMNS];//prepare the pixels in this array first then later copy everything to pixels[]
static pixel16_t pixels[NUM_COLUMNS];//each uint16_t stores 1 column of pixels

void delay_ms(uint16_t x){
	uint8_t y, z;
	for ( ; x > 0 ; x--){
		for ( y = 0 ; y < 90 ; y++){
			for ( z = 0 ; z < 6 ; z++){
				asm volatile ("nop");
			}
		}
	}
}

int main(void){
	DDRB=0b00101110;//Set PB1 (OE), PB2 (latch), 3 (MOSI) and 5 (CLK) as output (rows of leds)
	DDRD=0b11100110;//set PD1 (TXD), 5 (data), 6 (clock) and 7 (latch) as output (columns of leds) and PD2 LED for debugging
	SPCR=(1<<SPE)|(1<<MSTR)|(1<<SPR0)|(1<<DORD);//Fspi=fcpu/128 |(1<<DORD) to send LSb first
	
	//setup 8-bit timer/counter 0 in CTC mode (mode 2), F=fcpu/64, 
	/*
	TCCR0A=(1<<WGM01);
	TCCR0B=(1<<CS00)|(1<<CS01);
	OCR0A=249;
	TIMSK0=(1<<OCIE0A);
	*/
	
	//setup 16 bit timer/counter 1 in fast PWM mode (mode 14), F=fcpu/64, generates interrupt every ms, for refreshing one column of the screen every 1ms
	//this timer is also used to generate a PWM waveform on OC1A, which dims the display through the OE pin of the MBI5026
	TCCR1A=(1<<WGM11)|(1<<COM1A1);
	TCCR1B=(1<<WGM12)|(1<<WGM13)|(1<<CS10)|(1<<CS11);
	TCCR1C=0;
	ICR1=249;
	//OCR1A=224;//at 10% brightness
	//OCR1A=124;//at 50% brightness
	//OCR1A=24; //at 90% brightness, this is about maximum otherwise ghosting will appear
	TIMSK1=(1<<TOIE1);

	//setup 8 bit timer/counter 2 in CTC mode (mode 2), F=fcpu/1024, for the real time clock, generates interrupt every 8ms
	TCCR2A=(1<<WGM21);
	TCCR2B=(1<<CS20)|(1<<CS21)|(1<<CS22);
	OCR2A=124;
	TIMSK2=(1<<OCIE2A);

	sei();//enable interrupts

	//setup UART AT 115k2b/s for communication with the ESP01 (which communicates with wifi, internet and ntp time server)
	UCSR0A=(1<<U2X0); //double speed
	UCSR0B=(1<<RXEN0)|(1<<TXEN0)|(1<<RXCIE0);//enable tx & rx & enable interrupt on receive
	//UCSR0B=(1<<RXEN0)|(1<<TXEN0);//enable tx & rx
	UCSR0C=(1<<UCSZ00)|(1<<UCSZ01)|(1<<USBS0);//8 bit, 2 stop bits
	UBRR0=16;//set speed at 117k6 b/s, which is 2% high of 115k2
	print("Klok");
	
	
	//setup the ADC at 140kHz (16MHz/128), input is ADC0=PC0, reference is 1.1V
	//it is used for the Light Dependent Resistor (LDR) to determine ambient light level
	//when there is bright light, the LDR will have a low value and the voltage on ADC0 will be low (say, 0.4V)
	//when there is darkness, the LDR will have a high value and the voltage on ADC0 will be high (1.1V max)
	ADCSRA=(1<<ADEN)|(1<<ADPS0)|(1<<ADPS1)|(1<<ADPS2);
	ADMUX=(1<<REFS0)|(1<<REFS1);
	ADCSRA|=(1<<ADSC);//start conversion
	
	//get settings from eeprom
	anim_speed=eeprom_read_byte((uint8_t*)EEPROM_ANIM_SPEED);
	if(anim_speed==255) anim_speed=165;
	anim_delay=255-anim_speed;
	anim_delay*=anim_delay;
	
	anim_style=eeprom_read_byte((uint8_t*)EEPROM_ANIM_STYLE);
	if(anim_style>2)anim_style=1;
	
	if(eeprom_read_byte((uint8_t*)EEPROM_DST_ENABLED))dst_enabled=1;
	
	timezone=eeprom_read_byte((uint8_t*)EEPROM_TIMEZONE);
	if(timezone>25)timezone=1;
	
	uint8_t b=eeprom_read_byte((uint8_t*)EEPROM_BRIGHTNESS);
	if(b!=255){
		brightnessFixed=1;
		OCR1A=255-b;
	}
	
	five_min_style=eeprom_read_byte((uint8_t*)EEPROM_FIVEMINSTYLE);
	if(five_min_style>2)five_min_style=0;

	for(uint8_t k=0; k<NUM_COLUMNS; k++) pixels[k]=0;

    while(1){
		if(displayMode==0)displayTime();
		else{
			uint8_t what=tic-displayIpIndex;
			what/=2;
			if(what<2)display_text_ipadress();
			else displayNumber(ipadress[what-2]);
			if(what==6)displayMode=0;
		}
		static uint8_t readidx=0;
		if(readidx!=buffyIndex){
			checkSerialinput(buffy[readidx]);
			readidx++;
			cli();
			if(readidx==buffyIndex){
				//all characters processed, reset both indexes to 0
				readidx=0;
				buffyIndex=0;
			}
			sei();
		}
		if(!brightnessFixed)checkLdr();
	}
}

void checkSerialinput(char k){
	//check serial port input. We expect "<T22:23:24> or "<D2017-12-31>"
	if(k=='<'){
		bufindex=0;
		printchar(k);
		
	}else if (bufindex!=255){
		if(k=='>'){
			buf[bufindex++]=k;
			buf[bufindex]=0;
			//now do something with the string received!
			//echo it
			print(buf);
			if(buf[0]=='T'){
				//do syntax check: should be like T22:23:24>
				//Let op: dit is UTC!
				if ((buf[1]>'2')||(buf[1]<'0')||(buf[2]>'9')||(buf[2]<'0')||(buf[3]!=':')||
					(buf[4]>'5')||(buf[4]<'0')||(buf[5]>'9')||(buf[5]<'0')||(buf[6]!=':')||
					(buf[7]>'5')||(buf[7]<'0')||(buf[8]>'9')||(buf[8]<'0')||(buf[9]!='>')||
					((buf[1]=='2')&&(buf[2]>'3'))){
						//syntax error!
						printchar('E');
				}else{
					//syntax is ok
					printchar('K');
					cli();//temporarily disable interrupts
					//set the time
					uur=10*(buf[1]-'0') + buf[2]-'0'; //waarden: 0..23
					min=10*(buf[4]-'0') + buf[5]-'0';
					sec=10*(buf[7]-'0') + buf[8]-'0';
					sei();
				}
			} else if(buf[0]=='D'){
				//do syntax check: should be like D2017-02-31>
				if ((buf[1]!='2')||(buf[2]!='0')||(buf[3]>'9')||(buf[3]<'0')||(buf[4]>'9')||(buf[4]<'0')||(buf[5]!='-')||
				(buf[6]>'1')||(buf[6]<'0')||(buf[7]>'9')||(buf[7]<'0')||(buf[8]!='-')||
				(buf[9]>'3')||(buf[9]<'0')||(buf[10]>'9')||(buf[10]<'0')||(buf[11]!='>')||
				((buf[6]=='1')&&(buf[7]>'2'))||
				((buf[9]=='3')&&(buf[10]>'1'))){
					//syntax error!
					printchar('E');
				}else{
					//syntax is ok
					printchar('K');
					//set the date
					jaar=10*(buf[3]-'0') + (buf[4]-'0');
					maand=10*(buf[6]-'0') + (buf[7]-'0');
					dag=10*(buf[9]-'0') + (buf[10]-'0');
							
				}
			} else if(buf[0]=='I'){
				//DO SYNTAX CHECK: should be like IC0A80068>
				uint8_t ok= (buf[9]=='>');
				for(uint8_t i=1; i<=8; i++){
					if(buf[i]>='A' && buf[i]<='F') buf[i]+=10-'A'; else buf[i]-='0';
					if(buf[i]>0xf) ok=0;
				}
				if(ok){
					//syntax is ok
					printchar('K');
					uint8_t j=1;
					uint8_t changed=0;
					for(uint8_t i=0; i<4; i++) {
						uint8_t b=16*buf[j++];
						b+=buf[j++];
						if(b!=ipadress[i]){
							changed=1;
							ipadress[i]=b;
						}
					}
					if(changed){
						displayMode=1;
						displayIpIndex=tic;
					}
				}else printchar('E');
			} else if(buf[0]=='S'){
				//status request, answer with status
				print("{\"ver\":\"");
				print(SOFTWARE_VERSION);
				print("\",\"ti\":\"");
				printint2(20);
				printint2(jaar);
				printchar('-');
				printint2(maand);
				printchar('-');
				printint2(dag);
				printchar('T');
				printint2(uur+timezone+dst);
				printchar(':');
				printint2(min);
				printchar(':');
				printint2(sec);
				printchar('+');
				printint2(timezone+dst);
				printint2(0);
				print("\",\"ip\":\"");
				printuint(ipadress[0]);
				printchar('.');
				printuint(ipadress[1]);
				printchar('.');
				printuint(ipadress[2]);
				printchar('.');
				printuint(ipadress[3]);
				print("\",\"anistl\":");
				printuint(anim_style);
				print(",\"anisp\":");
				printuint(anim_speed);
				print(",\"zone\":");
				printuint(timezone);
				print(",\"dst\":");
				printuint(dst);
				print(",\"dste\":");
				printuint(dst_enabled);
				print(",\"bri\":");
				if(brightnessFixed)printuint(255-OCR1A);
				else print("\"a\"");
				print(",\"five\":");
				printuint(five_min_style);
				print("}</S>");
			} else if(buf[0]=='P'){
				//this is the PUT command, to set parameters in the clock.
				//general syntax: <P key=value>
				
				//try to interpret value as a decimal number
				uint8_t i=4;
				uint8_t value=0;
				while(buf[i]>='0' && buf[i]<='9') value=value*10+buf[i++]-'0';
				
				if(buf[2]=='a' && buf[4]>='0' && buf[4]<='3'){
					//set animation style: <P a=2>
					anim_style=buf[4]-'0';
					eeprom_update_byte((uint8_t*)EEPROM_ANIM_STYLE, anim_style);
				}
				if(buf[2]=='b'){//brightness: <P b=0> (light off) <P b=7> (minimum visible in the dark) <P b=230> (maximum without ghosting effect) or <P b=auto>
					brightnessFixed= buf[4]!='a';
					if(brightnessFixed) {
						OCR1A=255-value;
						eeprom_update_byte((uint8_t*)EEPROM_BRIGHTNESS, value);
					}else{
						eeprom_update_byte((uint8_t*)EEPROM_BRIGHTNESS, 255);
					}
				}
				if(buf[2]=='d'){//<P d=1> sets dst (zomertijd) enabled
					dst_enabled=(buf[4]!='0');
					eeprom_update_byte((uint8_t*)EEPROM_DST_ENABLED, dst_enabled);
				}
				if(buf[2]=='s'){//<P s=99> sets animation speed. The higher the number the faster
					eeprom_update_byte((uint8_t*)EEPROM_ANIM_SPEED, value);
					anim_speed=value;
					value=255-value;
					anim_delay= value*value;
				}
				if(buf[2]=='z'){//<P z=1> sets timezone
					timezone=value;
					eeprom_update_byte((uint8_t*)EEPROM_TIMEZONE, timezone);
				}
				if(buf[2]=='f' && value<=2){//<P f=1> sets five minutes style
					five_min_style=value;
					eeprom_update_byte((uint8_t*)EEPROM_FIVEMINSTYLE, five_min_style);
				}
			}
			bufindex=255;
		}else{
			if(bufindex<11){
				buf[bufindex++]=k;
			}else{
				//error: ">" not received in time!
				bufindex=255;
				//print(buf);
				//printchar('E');
			}
		}
	}
}

void checkLdr(){
	if(!(ADCSRA&(1<<ADSC))){//ADC conversion complete
		numLdrSamples++;
		sumLdrSamples+=ADC;
		ADCSRA|=(1<<ADSC);//start new conversion
		if(numLdrSamples==10){
			//uint16_t ldr=sumLdrSamples/30;
			uint16_t ldr=sumLdrSamples/29;
			//if(ldr<141)ldr=141;
			if(ldr<130)ldr=130;
			ldr-=117;
			OCR1A=ldr;
			numLdrSamples=0;
			sumLdrSamples=0;
			/*
			Voorschakelweerstand van 120k Ohm naar 3.3V
			light  | LDR | U(V) | ADC | sumLdr | PWM
			-------+-----+------+-----+--------+-----
			bright | 16k | 0.39 | 363 | 3630   |  24
			medium | 40k | 0.825| 768 | 7680   | 139
			dark   | 60k | 1.1  |1023 |10230   | 224
			*/
		}
	}
}

void setwoord(uint8_t woord, pixel16_t*matrix){
	uint8_t index=3*woord;
	uint8_t row= coordinaten[index];index++;
	uint8_t column= coordinaten[index];index++;
	uint8_t length= coordinaten[index];
	uint16_t pattern= 1<<(row+3);
	uint8_t col=column;
	while(length>0){
		matrix[col++] |= pattern;
		length--;
	}
}

void displayTime(){
	static uint8_t prevsec=0;
	uint8_t newsec=sec;
	if(newsec!=prevsec){
		prevsec=newsec;
		for (uint8_t i=0; i<NUM_COLUMNS; i++) mypixels[i]=0;
		
		setwoord(HET, mypixels);
		setwoord(IS, mypixels);
	
		if(KLKDBG){
			printchar(10);
			printchar(13);
			printint2(20);
			printint2(jaar);
			printchar('-');
			printint2(maand);
			printchar('-');
			printint2(dag);
			printchar('T');
			printint2(uur);
			printchar(':');
			printint2(min);
			printchar(':');
			printint2(sec);
			printchar('+');
			printint2(timezone+dst);
			printint2(0);
			printchar(' ');
			print("HET IS ");
		}
		dst=calcDST();
		uint8_t urenweergave=uur+timezone+dst;
		uint8_t min_afgerond;
		int8_t min_afronding;
		switch(five_min_style){
			case 1: min_afgerond=(min/5)*5; break;
			case 2: min_afgerond=((min+2)/5)*5; break;
			default: min_afgerond=min; break;
		}
		min_afronding=min-min_afgerond;
		if(min_afgerond==60){
			min_afgerond=0;
			urenweergave++;
		}
		if(min_afgerond==0){
			setwoord(UUR, mypixels);
			if(KLKDBG)print("UUR ");
		}
		else{
			uint8_t minutenweergave=min_afgerond%30;
			if(minutenweergave!=0){
				if(minutenweergave>15) minutenweergave=30-minutenweergave;
				setwoord(minutenweergave, mypixels);
				if(KLKDBG){
					printchar('0'+(minutenweergave/10));
					printchar('0'+(minutenweergave%10));
					printchar(' ');
				}
			}
			if(minutenweergave!=0){
				if((min_afgerond<=15)||((min_afgerond>30)&&(min_afgerond<45))){
					setwoord(OVER, mypixels);
					if(KLKDBG)print("OVER ");
				}else{
					setwoord(VOOR, mypixels);
					if(KLKDBG)print("VOOR ");
				}
			}
			if((min_afgerond>15)&&(min_afgerond<45)){
				setwoord(HALF, mypixels);
				if(KLKDBG)print("HALF ");
			}
		}
		if(min_afgerond>15)urenweergave++;
		urenweergave=(urenweergave+11)%12+1;
		setwoord(UREN_OFFSET+urenweergave, mypixels);
		if(KLKDBG)printint2(urenweergave);

		//De vier 15seconden-LED's, zet zowel direct in pixels als in mypixels
		pixels[0]&=~(1<<3);
		pixels[1]&=~(1<<3);
		pixels[11]&=~(1<<3);
		pixels[12]&=~(1<<3);
		if(five_min_style!=0){
			if(min_afronding<0){
				setwoord(SEC45_59, mypixels);
				setwoord(SEC45_59, pixels);
				//een en twee minuten voor het hele en halve uur, toon ook de tekst "even voor"
				if(LEUK && min_afgerond%30==0){
					setwoord(EVEN,mypixels);
					setwoord(VOOR,mypixels);
				}
			}
			if(min_afronding==-2){
				setwoord(SEC30_44, mypixels);
				setwoord(SEC30_44, pixels);
			}
			if(LEUK && min_afronding>0 && min_afgerond%30==0){
				setwoord(NA, mypixels);
			}
			while(min_afronding>0){
				min_afronding--;
				setwoord(min_afronding+SEC00_14, mypixels);
				setwoord(min_afronding+SEC00_14, pixels);
			}
		}else{
			setwoord((sec/15)+SEC00_14, mypixels);
			setwoord((sec/15)+SEC00_14, pixels);
		}
		if(KLKDBG){
			printchar('s');
			printchar('0'+(sec/15));
		}
	}
	if(anim_style==0){
		for(uint8_t i=0; i<NUM_COLUMNS; i++){
			pixels[i]=mypixels[i];
		}
	}else{
		static uint16_t slow=0;
		slow++;
		if(slow==anim_delay){
			slow=0;
			if(anim_style==3){//rain style
				//uint8_t col=rand()%NUM_COLUMNS;
				for(uint8_t col=0; col<NUM_COLUMNS; col++){
					//zoek eerste verschil in deze kolom
					uint16_t ist=pixels[col];
					uint16_t soll=mypixels[col];
					uint8_t row=4;
					uint16_t diff=(ist ^ soll)>>row;
					while((diff&1)==0 && row<16){diff=diff>>1;row++;}
					if(row!=16){//verschil gevonden in row 
						if((soll>>row)&1){//er moet een led aangezet worden op row
							//injecteer een brandende pixel van bovenaf
							//doe dit niet altijd, zodat een random effect ontstaat
							if(rand()%5==0){
								//zoek eerste lege pixel
								row=4;
								ist=ist>>row;
								while((ist&1)==1 && row<16){ist=ist>>1;row++;}
								pixels[col]|=(1<<row);
							}
						}else{//er moet een led uitgezet worden op row
							//zoek eerste lege pixel daaronder
							ist=ist>>row;
							while((ist&1)==1 && row<16){ist=ist>>1;row++;}
							//row is nu de eerste niet brandende
							if(row<16)pixels[col]|=(1<<row);
							row--;//row is nu de laatste brandende
							pixels[col]&=~(1<<row);
						}
					}
				}
			}else{//snail and snake style
				//vergelijk mypixels (de gewenste weergave) met pixels (de huidige weergave). Doe dit pixel voor pixel. Vind je een verschil, verschuif dan een beetje zodat
				//pixels iets beter gaat lijken op mypixels
				//zoek het eerste verschil
				uint8_t i;
				for(i=0;i<12*13; i++){
					if (getlin(i,pixels)!=getlin(i,mypixels)) break;
				}
				if(i<12*13){//zijn er uberhaupt verschillen?
					if(getlin(i,mypixels)){//schuif een 1 naar links
						uint8_t j=i;
						while((getlin(j,pixels)==0) && j<12*13)j++;//zoek de 1
						if(j<12*13){
							setlin(j,0,pixels);
							uint8_t row=j/13;
							uint8_t l=26*row-j;
							//if(j-i>=25 && anim_style==1){//doe een verschuiving omhoog ipv opzij
							if(row>0 && l>i && anim_style==1){//doe een verschuiving omhoog ipv opzij
								j=l;
							}
						}
						setlin(j-1,1,pixels);
					}else{//schuif een een naar rechts
						uint8_t j=i;
						while((getlin(i,pixels)==1)&&i<12*13)i++;//zoek de 0
						if(i<12*13) setlin(i,1,pixels);
						setlin(j,0,pixels);
					}
				}
			}
		}
	}
}
	
void displayNumber(uint8_t n){
	//display a number (0..254) on the wordclock
	//this is intended to be used to display the ip-address of the clock
	for(uint8_t i=0; i<NUM_COLUMNS; i++) mypixels[i]=0;
	if(n>0 && n<=14) setwoord(n, mypixels);
	else if(n>=210 && n<=212) setwoord(n-200,mypixels);
	else setwoord(UREN_OFFSET+(n%10), mypixels);
	if(n>=15 && n<=149) setwoord(n/10, mypixels);
	if(n>=150 && n<=199) {
		setwoord(1, mypixels);
		setwoord((n-100)/10, mypixels);
	}
	if(n>=200){
		setwoord(2, mypixels);
		if(n<=209)setwoord(NUL_EXTRA,mypixels);
		if(n>=213 && n<=219)setwoord(1+UREN_OFFSET, mypixels);
		if(n>=220 && n<=222){
			setwoord(T_FOR_TWEE,mypixels);
			setwoord(T_FOR_TWEE+1,mypixels);
			setwoord(T_FOR_TWEE+2,mypixels);
		}
		if(n>=223 && n<=229)setwoord(2+UREN_OFFSET,mypixels);
		if(n>=230)setwoord((n-200)/10, mypixels);
	}	
	for(uint8_t i=0; i<NUM_COLUMNS; i++) pixels[i]=mypixels[i];
}

//this function displays the text "adres ip" on the wordklok
void display_text_ipadress(){
	for(uint8_t i=0; i<NUM_COLUMNS; i++) mypixels[i]=0;
	setwoord(I_FOR_IP,mypixels);
	setwoord(I_FOR_IP+1,mypixels);
	setwoord(A_FOR_ADRES,mypixels);
	setwoord(A_FOR_ADRES+1,mypixels);
	setwoord(A_FOR_ADRES+2,mypixels);
	for(uint8_t i=0; i<NUM_COLUMNS; i++) pixels[i]=mypixels[i];
}

void printchar(char c){
	while ( !( UCSR0A & (1<<UDRE0)) ){};//wait before transmit
	UDR0=c;	
}

void print(char*s){
	while (*s)printchar(*(s++));
}

void printint2(uint8_t n){
	//print  a digit 00..99 in two decimal characters
	//digits between 100 and 255 are printed with the first digit :;<=>?@ABC... e.g. 200 is D0
	printchar('0'+n/10);
	printchar('0'+n%10);
}

void printuint(uint8_t n){
	//print  a digit 0..255 in decimal characters
	if (n>=100) printchar('0'+n/100);
	if (n>=10)	printchar('0'+(n%100)/10);
	printchar('0'+n%10);
}
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

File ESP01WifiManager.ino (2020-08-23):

#include <ESP8266WiFi.h>
#include <ESP8266mDNS.h>
#include <ESP8266WebServer.h>
#include <WiFiManager.h>
#include <TimeLib.h>

//remove the following defintion after development
//it is insecure, allows CORS!!
//SEE https://developer.mozilla.org/nl/docs/Web/HTTP/CORS/Errors/CORSMissingAllowOrigin
//#define CORS server.sendHeader("Access-Control-Allow-Origin", "*"); server.sendHeader("Access-Control-Allow-Methods", "GET,HEAD,PUT"); 
#define CORS

#define SERIALINBUFSIZE 3200

ESP8266WebServer server(80);    // Create a webserver object that listens for HTTP request on port 80
WiFiUDP UDPNTPClient;  
MDNSResponder mdns; //create a mdns domain name woordklok.local
// NTP Client
const int NTP_PACKET_SIZE = 48;
byte packetBuffer[NTP_PACKET_SIZE];
uint16_t numberOfNtpCalls=0;
uint16_t numberOfNtpSuccesses=0;
time_t lastNtpTime=0;
time_t firstNtpTime=0;
char version[]="2.1";

void handleRoot();
void handleEsp();
void handleStatus();
void handleSet();
void handleFavicon();
void handleNotFound();

void setup() {
  Serial.begin(115200);
  Serial.print ("WK: start with SSID: ");
  Serial.println(WiFi.SSID());
  //Serial.println(WiFi.psk()); //stored wireless password
  WiFiManager wifiManager;
  wifiManager.autoConnect("WoordklokSetup", "woordklokcharles");
  Serial.print("WK: Connected to ");
  Serial.println(WiFi.SSID());
  Serial.printf("Hostname: %s\n", WiFi.hostname().c_str());
  IPAddress ipa=WiFi.localIP();
  delay(10);
  Serial.print("<I");
  for(uint8_t i=0; i<4; i++){
    Serial.printf("%02X",ipa[i]);
    delay(1);
  }
  Serial.println(">");
  MDNS.begin("woordklok");
  MDNS.addService("http", "tcp", 80);
  
  server.on("/", handleRoot);
  server.on("/status", handleStatus);
  server.on("/esp", handleEsp);
  server.on("/set", handleSet);
  server.on("/favicon.ico", handleFavicon);
  server.onNotFound(handleNotFound);        // When a client requests an unknown URI
  server.begin();                           // Actually start the server
  Serial.println("HTTP server started");
}

void loop() {
  static int net=99;
  int s=minute(now())/10;
  if((s!=net)||(year(now())==1970)){
    NTPRefresh();
  }
  server.handleClient(); 
  net=s;
}

void handleEsp(){
  Serial.println("handleEsp");
  time_t t=now();
  char hh[145];
  sprintf(hh, "{\
\"ver\":\"%s\",\n\
\"ssid\":\"%s\",\n\
\"now\":\"%d-%02d-%02dT%d:%02dZ\",\n\
\"last\": \"%04d-%02d-%02dT%d:%02dZ\",\n\
\"first\": \"%04d-%02d-%02dT%d:%02dZ\",\n\
\"calls\": %d,\n\
\"successes\": %d}", 
    version, WiFi.SSID().c_str(),
    year(t), month(t), day(t), hour(t), minute(t), 
    year(lastNtpTime), month(lastNtpTime), day(lastNtpTime), hour(lastNtpTime), minute(lastNtpTime), 
    year(firstNtpTime), month(firstNtpTime), day(firstNtpTime), hour(firstNtpTime), minute(firstNtpTime), 
    numberOfNtpCalls, numberOfNtpSuccesses);
  CORS;
  server.sendHeader("Expires", "-1");
  server.send(200, "application/json", hh);
}

void handleStatus(){
  //first empty the serial input buffer
  while(Serial.available()>0){
    Serial.read();
  }
  //send status request
  Serial.print("<S>");

  //read the response
  static char buf[SERIALINBUFSIZE+3];
  char c;
  int i=0;
  int t=0;
  //wait for the "{"
  do {
    c=Serial.read();
    if(c==255){
      delay(10);
      t++;
    }
  }while((c!='{')&&(t<400));
  buf[0]=c;
  i++;

  //read until the "}"
  do {
    c=Serial.read();
    if(c!=255){
      buf[i]=c;
      i++;
    }else {
      //Serial.print(".");
      delay(10);
      t++;
    }
  }while((c!='}')&&(i<SERIALINBUFSIZE)&&(t<4000));
  CORS;
  server.sendHeader("Expires", "-1");
  if(i>1){
    buf[i]=0; 
    server.send(200, "text/plain", buf);
  }else{
    server.send(504, "text/plain", "Klok antwoordt niet");
  }
}

void handleSet(){
  CORS;
  if(server.args()==1){
    Serial.print("<P ");  
    Serial.print(server.argName(0));
    Serial.print("=");  
    Serial.print(server.arg(0));
    Serial.println(">");
    server.send(200, "text/plain", "Commando naar klok gestuurd");
  }else{
    server.send(400, "text/plain", "Een (1) query parameter nodig (/set?x=y)");
  }
}

void handleFavicon(){
  Serial.println("handleFavicon");
  CORS;
  server.send(200, "application/json", "");
}

void handleNotFound(){
  Serial.print("handleNotFound ");
  Serial.println(server.uri());
  CORS;
  server.send(404, "text/plain", "404: Not Found!");
}

void  NTPRefresh() {
  UDPNTPClient.begin(2390);  // Port for NTP receive
  String ntpServerName="0.de.pool.ntp.org";

  Serial.println("NTPRefresh");
  Serial.println(ntpServerName);
  if (WiFi.status() == WL_CONNECTED) {
    IPAddress timeServerIP;
    WiFi.hostByName(ntpServerName.c_str(), timeServerIP);
    numberOfNtpCalls++;
    Serial.println("Zending NTP packet... ");
    memset(packetBuffer, 0, NTP_PACKET_SIZE);
    packetBuffer[0] = 0b11100011;   // LI, Version, Mode
    packetBuffer[1] = 0;     // Stratum, or type of clock
    packetBuffer[2] = 6;     // Polling Interval
    packetBuffer[3] = 0xEC;  // Peer Clock Precision
    packetBuffer[12] = 49;
    packetBuffer[13] = 0x4E;
    packetBuffer[14] = 49;
    packetBuffer[15] = 52;
    UDPNTPClient.beginPacket(timeServerIP, 123);
    UDPNTPClient.write(packetBuffer, NTP_PACKET_SIZE);
    UDPNTPClient.endPacket();

    delay(1000);
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

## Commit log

2018-06-21 Versie met animatie lopende letters
    Bug rond 1 uur gefixt
    [WoordKlokCharles.c]
2018-07-09 Bug in de definitie van het woord EEN gecorrigeerd
    [WoordKlokCharles.c]
2018-07-31 CADSoft Eagle pcb design files for version 1 of the pcb
    [WoordklokCharles.brd, WoordklokCharles.sch]
2018-07-31 Image of the unpopulated pcb
2018-07-31 Photo of the unpopulated printed circuit board (pcb)
2018-07-31 Photo of the pcb populated and installed in the Woordklok
2018-07-31 Schema hoe de LEDs aan te sluiten
2018-07-31 Electronic schematic diagram
2018-12-30 2.0 versie van de woordklok
2019-02-02 V3.0 of CADsoft Eagle files,
    V3.0: changed IC3 to MCP1702-33
    V2.0: added pull-up resistors for ESP01, several minor corrections
    [WoordklokCharles.brd, WoordklokCharles.sch]
2020-08-23 Fixed problem with zero NTP leading to 07:28
    Issue: If the 32-bit time value in the NTP packet contains all zeroes, this is interpreted as 2036-02-07T06:28:18Z. Therefore, the clock is set to the wrong time (to 7:28 in CET).
    In applications where a wake up call is used, if it is set to 7:30, the alarm will go off after two minutes, which is annoying.
    Solution: check for the time value being 0. If so, ignore it.
    [ESP01WifiManager.ino]
2022-02-28 Originele handleiding v.d. mechanische opbouw 2016
    Omdat de oorspronkelijke handleiding op de website http://wordclock_old.protoart.net niet meer te vinden is, voor degenen die na al die jaren nog steeds de doos ongeopend op zolder hebben staan, hier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

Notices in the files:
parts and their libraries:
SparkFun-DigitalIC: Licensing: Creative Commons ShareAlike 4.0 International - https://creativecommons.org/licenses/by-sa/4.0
